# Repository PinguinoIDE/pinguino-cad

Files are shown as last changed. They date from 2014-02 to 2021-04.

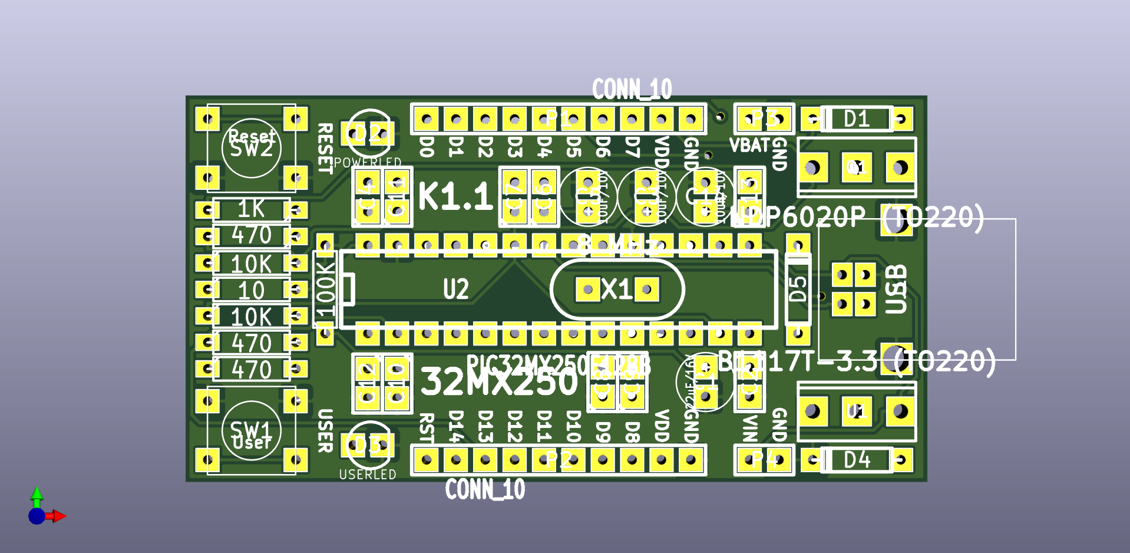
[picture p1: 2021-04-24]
boards/32MX250/K1.1/32mx2xx.png

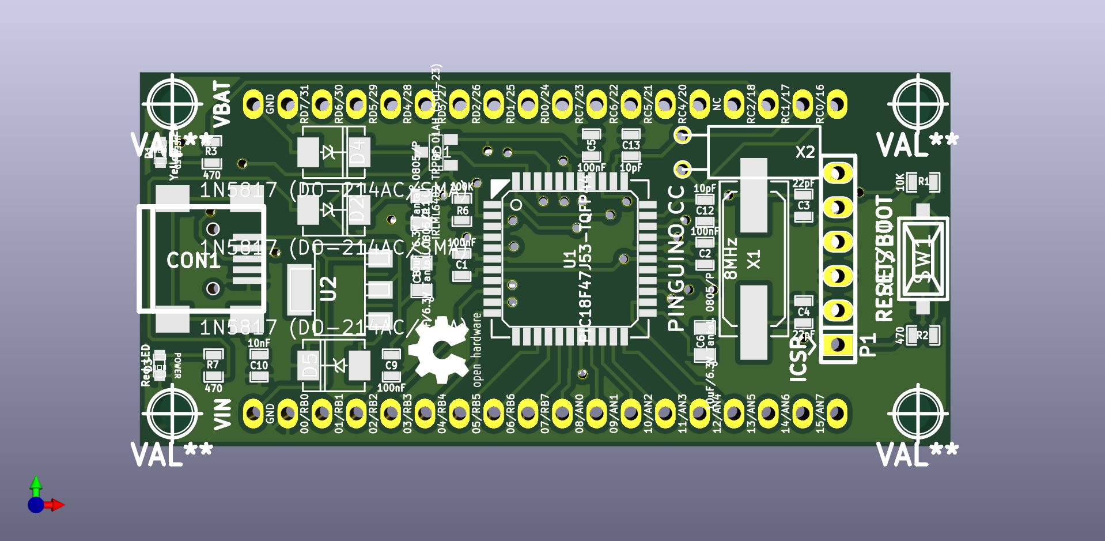
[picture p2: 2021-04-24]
boards/47J53/A1.2/Pinguino47j53A.png

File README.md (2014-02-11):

Most of the Pinguino boards or extensions are designed with Kicad.

KiCad is an EDA software suite for the creation of professional schematics and printed circuit boards up to 16 layers. KiCad runs on Windows, Linux and Apple OS X and is released under the open-source GNU GPL v2 free of charge. With Kicad you can do the following :

<ul>
<li>Schematic design.
<li>Netlist creation in multiple formats (PCBNew, OrCAD, CadStar, Spice, etc...).
<li>PCB design
<li>3D visualization of your PCB
<li>Fabrication outputs generation (Gerber, drill files and whatever can be needed to manufacture a PCB.)
</ul>

For a more detailed explanation please refer to the official site : http://www.kicad-pcb.org

For a better result we use libraries, modules en 3D packages from Walter : http://smisioto.no-ip.org/elettronica/kicad/kicad-en.htm

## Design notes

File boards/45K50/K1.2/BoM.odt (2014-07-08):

### Pinguino 45K50

### Bill Of Components

Resistors

- 3 x 470 Ohm (Yellow - Purple - Black - Black)
- 1 x 10K Ohm (Brown - Black - Orange)

Capacitors

- 2 x 100nF (marked as 104)
- 1 x 220nF (marked as 224)

Diodes

- 1 x 3mm Red LED (+/anode = long lead)
- 1 x 3mm Yellow LED (+/anode = long lead)

Connectors

- 1 x USB Type-B Female
- 1 x 40-pin 2.54mm header strip
- 1 x 40-pin 2.54mm round female header strip)
- Others
- 1 x 2-pin Push Button
- 1 x PIC18F45K50
- 1 x PCB

Optional

- 1 x 8 MHz crystal
- 2 x 22pF (marked as 22)
- 1 x 22uF (polarized, marked as 10uF)
- 1 x 100nF (marked as 104)
- 1x LM7805

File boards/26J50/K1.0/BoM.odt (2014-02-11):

### Bill Of Components

Resistors

- 2 x 470 Ohm (Yellow - Purple - Black - Black)
- 1 x 10 Ohm (Brown - Black - Black - Gold)
- 1 x 10K Ohm (Brown - Black - Orange)

Capacitors

- 2 x 22pF (marked as 22)
- 1 x 10uF (polarized, marked as 10uF)
- 2 x 100nF (marked as 104)

Diodes

- 1 x 3mm Red LED (+/anode = long lead)
- 1 x BZX85C3V3 (3.3V Zener Diode, NB: black band denotes cathode)

Connectors

- 1 x USB Type-B Female
- 1 x 40-pin 2.54mm header strip
- 1 x 40-pin 2.54mm round female header strip)

Others

- 1 x Push Button
- 1 x 8- or 20 MHz crystal
- 1 x PIC18F26J50
- 1 x PCB

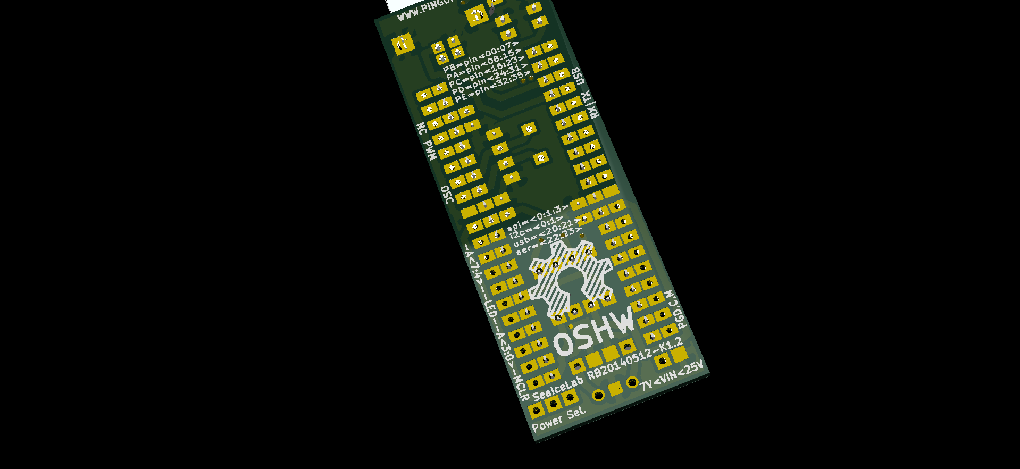
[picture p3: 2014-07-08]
boards/45K50/K1.2/Pinguino45K50-B.png

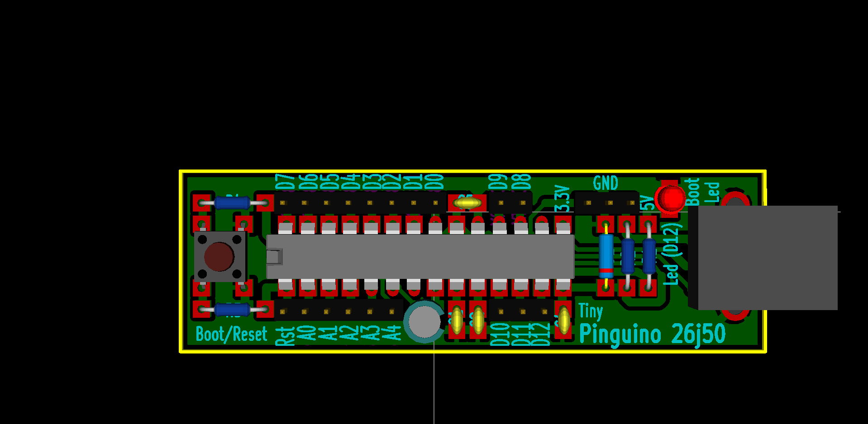
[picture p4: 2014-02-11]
boards/26J50/K1.0/Pinguino26j50.png

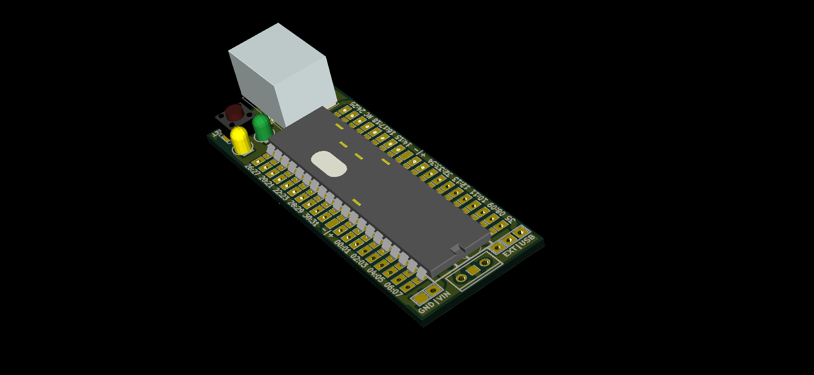
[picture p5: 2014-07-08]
boards/45K50/K1.2/Pinguino45K50-F.png

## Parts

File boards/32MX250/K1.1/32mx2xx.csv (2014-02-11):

Id | Référence | Boitier | Quantité | Désignation | Fournisseur et réf.
1 | D2 | LED-3MM | 1 | POWERLED
2 | D3 | LED-3MM | 1 | USERLED
3 | P2,P1 | SIL-10 | 2 | CONN_10
4 | C7,C10,C12,C13,C2,C4,C6,C11 | C1 | 8 | 100nF
5 | C8,C9 | C1 | 2 | 22pF
6 | D4,D5,D1 | D3 | 3 | 1N5817 (DO-214AC)
7 | P3,P4 | SIL-2 | 2 | Ext. Power
8 | R1 | R3 | 1 | 100K
9 | R2 | R3 | 1 | 1K
10 | R3,R7,R8 | R3 | 3 | 470
11 | R4 | R3 | 1 | 10
12 | R5,R6 | R3 | 2 | 10K
13 | SW1 | SW_PUSH_SMALL | 1 | User
14 | SW2 | SW_PUSH_SMALL | 1 | Reset
15 | X1 | HC-49V | 1 | 8 MHz
16 | C1 | C1V5 | 1 | 22uF/16V
17 | C3,C5,C14 | C1V5 | 3 | 10uF/10V
18 | G2 | Logo_silk_OSHW_6x6mm | 1 | LOGO
19 | J1 | USB_B | 1 | USB
20 | Q1 | to220 | 1 | NDP6020P (TO220)
21 | U1 | to220 | 1 | B1117T-3.3 (TO220)
22 | U2 | dil_28-300 | 1 | PIC32MX250F128B
23 | VAL | logo1in | 1 | logo1in
24 | G*** | Logo_silk_WEEE_3.4x5mm | 1 | LOGO

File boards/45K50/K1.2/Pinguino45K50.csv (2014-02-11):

Id | Référence | Boitier | Quantité | Désignation | Fournisseur et réf.
1 | P6 | pin_strip_6 | 1 | PORT_A
2 | C1,C2 | cnp_3mm_disc | 2 | 22pF
3 | C3 | CP_5x11mm | 1 | 10uF
4 | C4 | cnp_7x6mm | 1 | 220nF
5 | C5 | cnp_3mm_disc | 1 | 100nF
6 | J1 | conn_usb_B | 1 | USB-B
7 | K1 | pin_strip_3 | 1 | PWM
8 | P3 | pin_strip_2 | 1 | UART
9 | P4 | pin_strip_8 | 1 | PORT_B
10 | P5 | pin_strip_2 | 1 | +/-
11 | R1 | RC03 | 1 | 10K
12 | R2 | RC03 | 1 | 470
13 | SW1 | PCB_PUSH | 1 | But
14 | U1 | dil_28-300_socket | 1 | PIC18F2550
15 | X1 | crystal_hc-49u | 1 | 20MHz
16 | D1 | led_3mm_red | 1 | Led

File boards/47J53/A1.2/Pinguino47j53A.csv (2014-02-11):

Id | Référence | Boitier | Quantité | Désignation | Fournisseur et réf.
1 | C6,C11,C8 | c_0805 | 3 | 10uF/6.3V Tantal. 0805/P
2 | J1,J2 | pin_strip_20 | 2 | HEADER_20
3 | C4,C3 | SM0603_Capa | 2 | 22pF
4 | C2,C1,C5,C9,C7 | SM0603_Capa | 5 | 100nF
5 | D1 | LED-0603 | 1 | Yellow LED
6 | U1 | lqfp44 | 1 | PIC18F47J53-TQFP44
7 | D3 | LED-0603 | 1 | Red LED
8 | R3,R2,R7 | SM0603_Resistor | 3 | 470
9 | R1 | SM0603_Resistor | 1 | 10K
10 | R5,R4,R6 | SM0603_Resistor | 3 | 100K
11 | SW1 | smd_push | 1 | RESET
12 | LOGO1 | LOGO | 1 | OPEN_HARDWARE_1
13 | CON1 | USB_MINI_B | 1 | USB-MINI-B
14 | C10 | SM0603_Capa | 1 | 10nF
15 | D2,D4,D5 | DO-214AC(SMA) | 3 | 1N5817 (DO-214AC/SMA)
16 | X1 | Q_49U3HMS | 1 | 8MHz
17 | P1 | pin_strip_6 | 1 | ICSP
18 | U2 | sot223 | 1 | AMS1117-3.3V (SOT-223)
19 | U6 | Logo_silk_WEEE_8x10mm | 1 | DIAMOND1
20 | U3 | Logo_silk_OSHW_6x6mm | 1 | DIAMOND1
21 | Q1 | SOT23 | 1 | IRLML6402 TRPBF 01AH (SOT-23)
22 | hole_3mm_1,hole_3mm_4,hole_3mm_2,hole_3mm_3 | hole_3mm | 4 | VAL**
23 | C12,C13 | SM0603_Capa | 2 | 10pF
24 | X2 | QMONTRE | 1 | 32768Hz

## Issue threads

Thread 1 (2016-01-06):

Wrong board?

josla972, 2016-01-06:
When I open Pinguino45K50.brd in Pcbnew, the layout seems to differ from the PCB shown on the wiki pages. Also, it says PIC18F26J50 on the board which is not the correct PIC processor.

rblanchot, 2016-01-11:
Hi,
Sorry for the late response,
The correct file is Pinguino45K50.kicad_pcb

Closed 2016-01-11.

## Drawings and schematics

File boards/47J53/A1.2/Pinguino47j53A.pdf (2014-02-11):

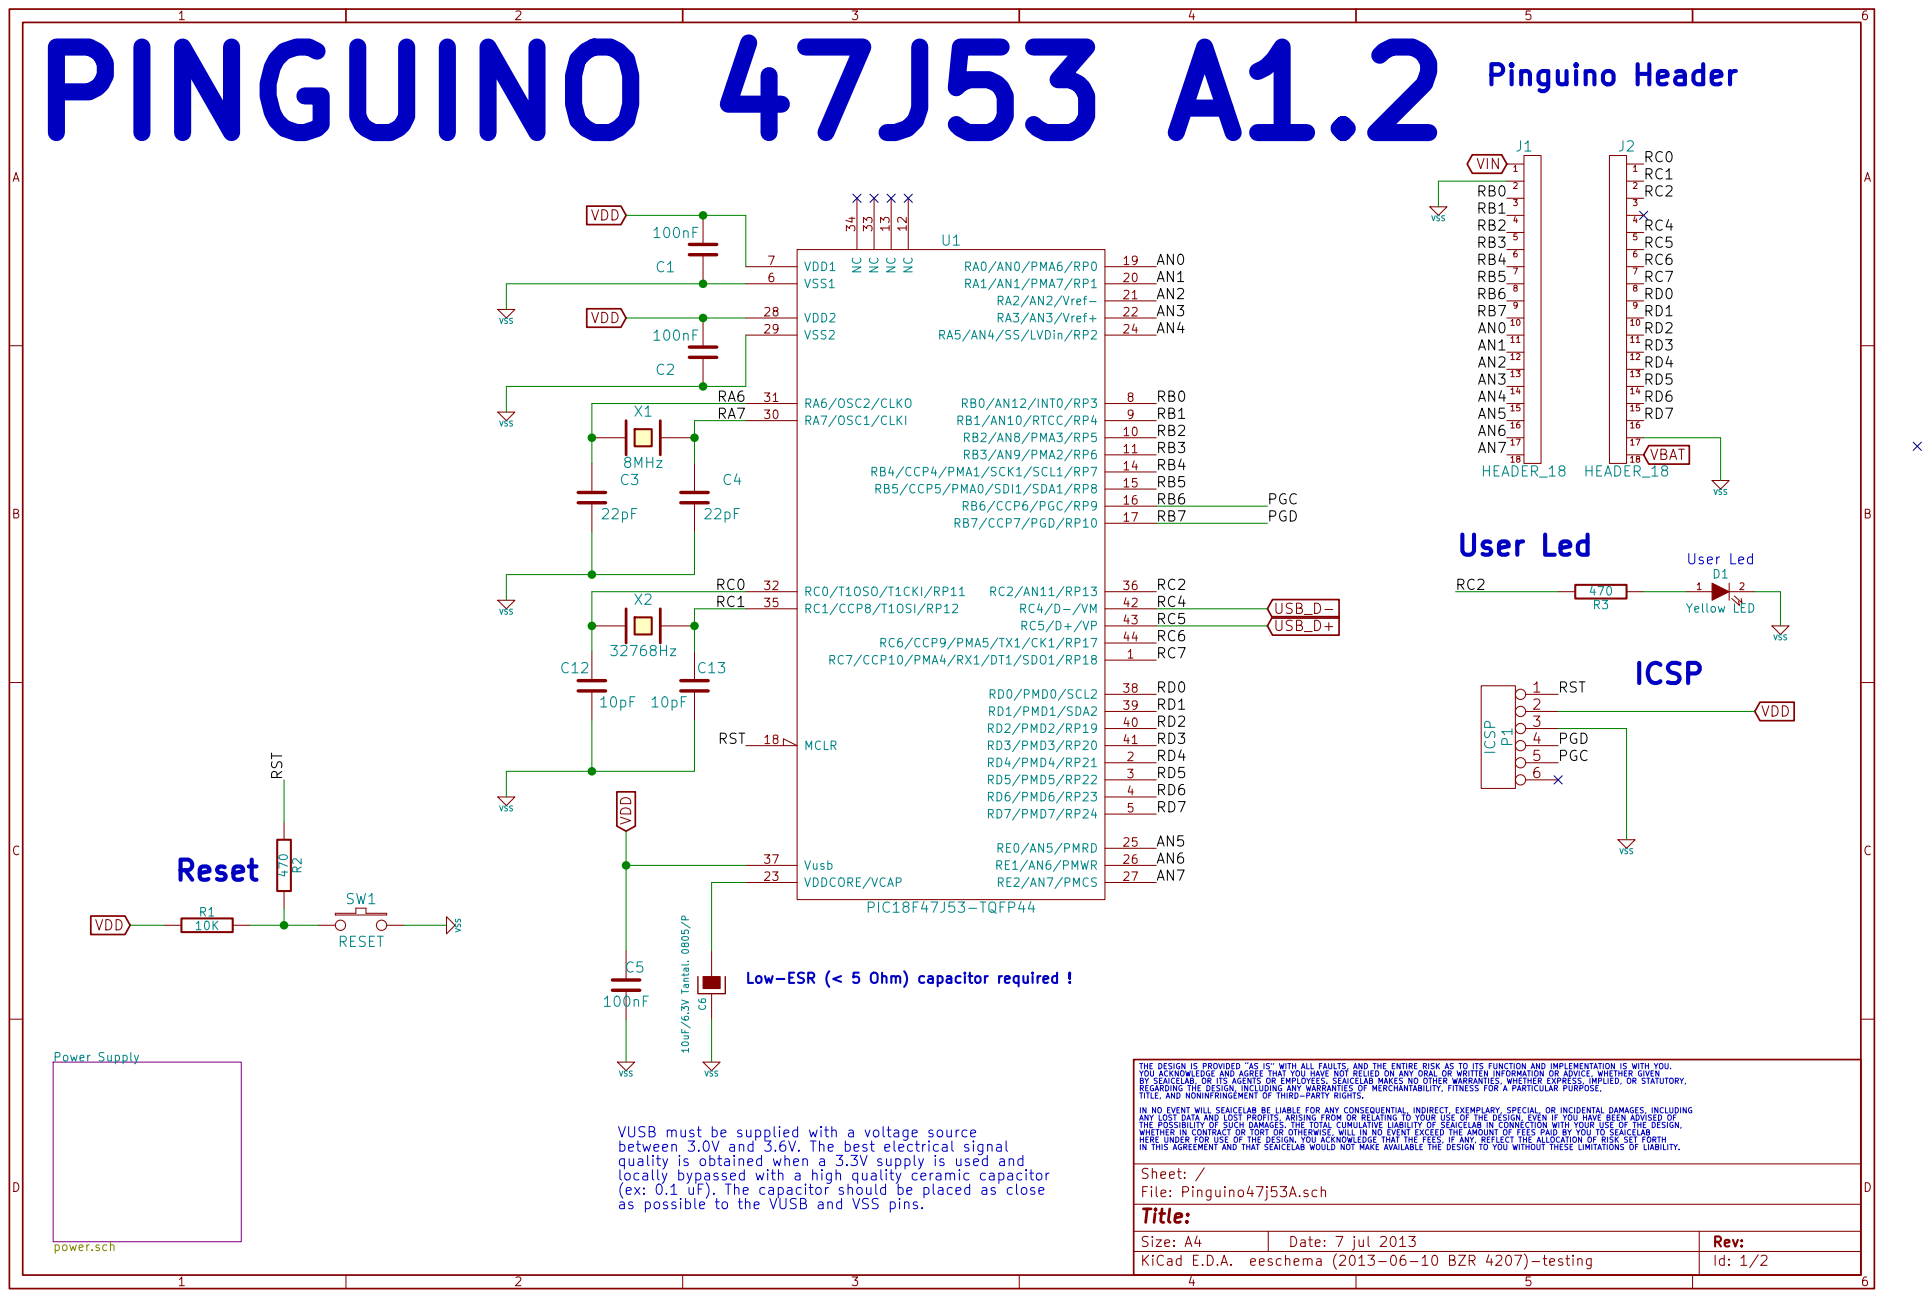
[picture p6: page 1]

100nF VUSB must be supplied with a voltage source

THE DESIGN IS PROVIDED AS IS WITH ALL FAULTS, AND THE ENTIRE RISK AS TO ITS FUNCTION AND IMPLEMENTATION IS WITH YOU. YOU ACKNOWLEDGE AND AGREE THAT YOU HAVE NOT RELIED ON ANY ORAL OR WRITTEN INFORMATION OR ADVICE, WHETHER GIVEN
BY SEAICELAB, OR ITS AGENTS OR EMPLOYEES. SEAICELAB MAKES NO OTHER WARRANTIES, WHETHER EXPRESS, IMPLIED, OR STATUTORY, REGARDING THE DESIGN, INCLUDING ANY WARRANTIES OF MERCHANTABILITY, FITNESS FOR A PARTICULAR PURPOSE, TITLE, AND NONINFRINGEMENT OF THIRD-PARTY RIGHTS.

IN NO EVENT WILL SEAICELAB BE LIABLE FOR ANY CONSEQUENTIAL, INDIRECT, EXEMPLARY, SPECIAL, OR INCIDENTAL DAMAGES, INCLUDING
ANY LOST DATA AND LOST PROFITS, ARISING FROM OR RELATING TO YOUR USE OF THE DESIGN, EVEN IF YOU HAVE BEEN ADVISED OF
THE POSSIBILITY OF SUCH DAMAGES. THE TOTAL CUMULATIVE LIABILITY OF SEAICELAB IN CONNECTION WITH YOUR USE OF THE DESIGN, WHETHER IN CONTRACT OR TORT OR OTHERWISE, WILL IN NO EVENT EXCEED THE AMOUNT OF FEES PAID BY YOU TO SEAICELAB HERE UNDER FOR USE OF THE DESIGN. YOU ACKNOWLEDGE THAT THE FEES, IF ANY, REFLECT THE ALLOCATION OF RISK SET FORTH

between 3.0V and 3.6V. The best electrical signal
quality is obtained when a 3.3V supply is used and
locally bypassed with a high quality ceramic capacitor
(ex: 0.1 uF). The capacitor should be placed as close
as possible to the VUSB and VSS pins.

IN THIS AGREEMENT AND THAT SEAICELAB WOULD NOT MAKE AVAILABLE THE DESIGN TO YOU WITHOUT THESE LIMITATIONS OF LIABILITY.

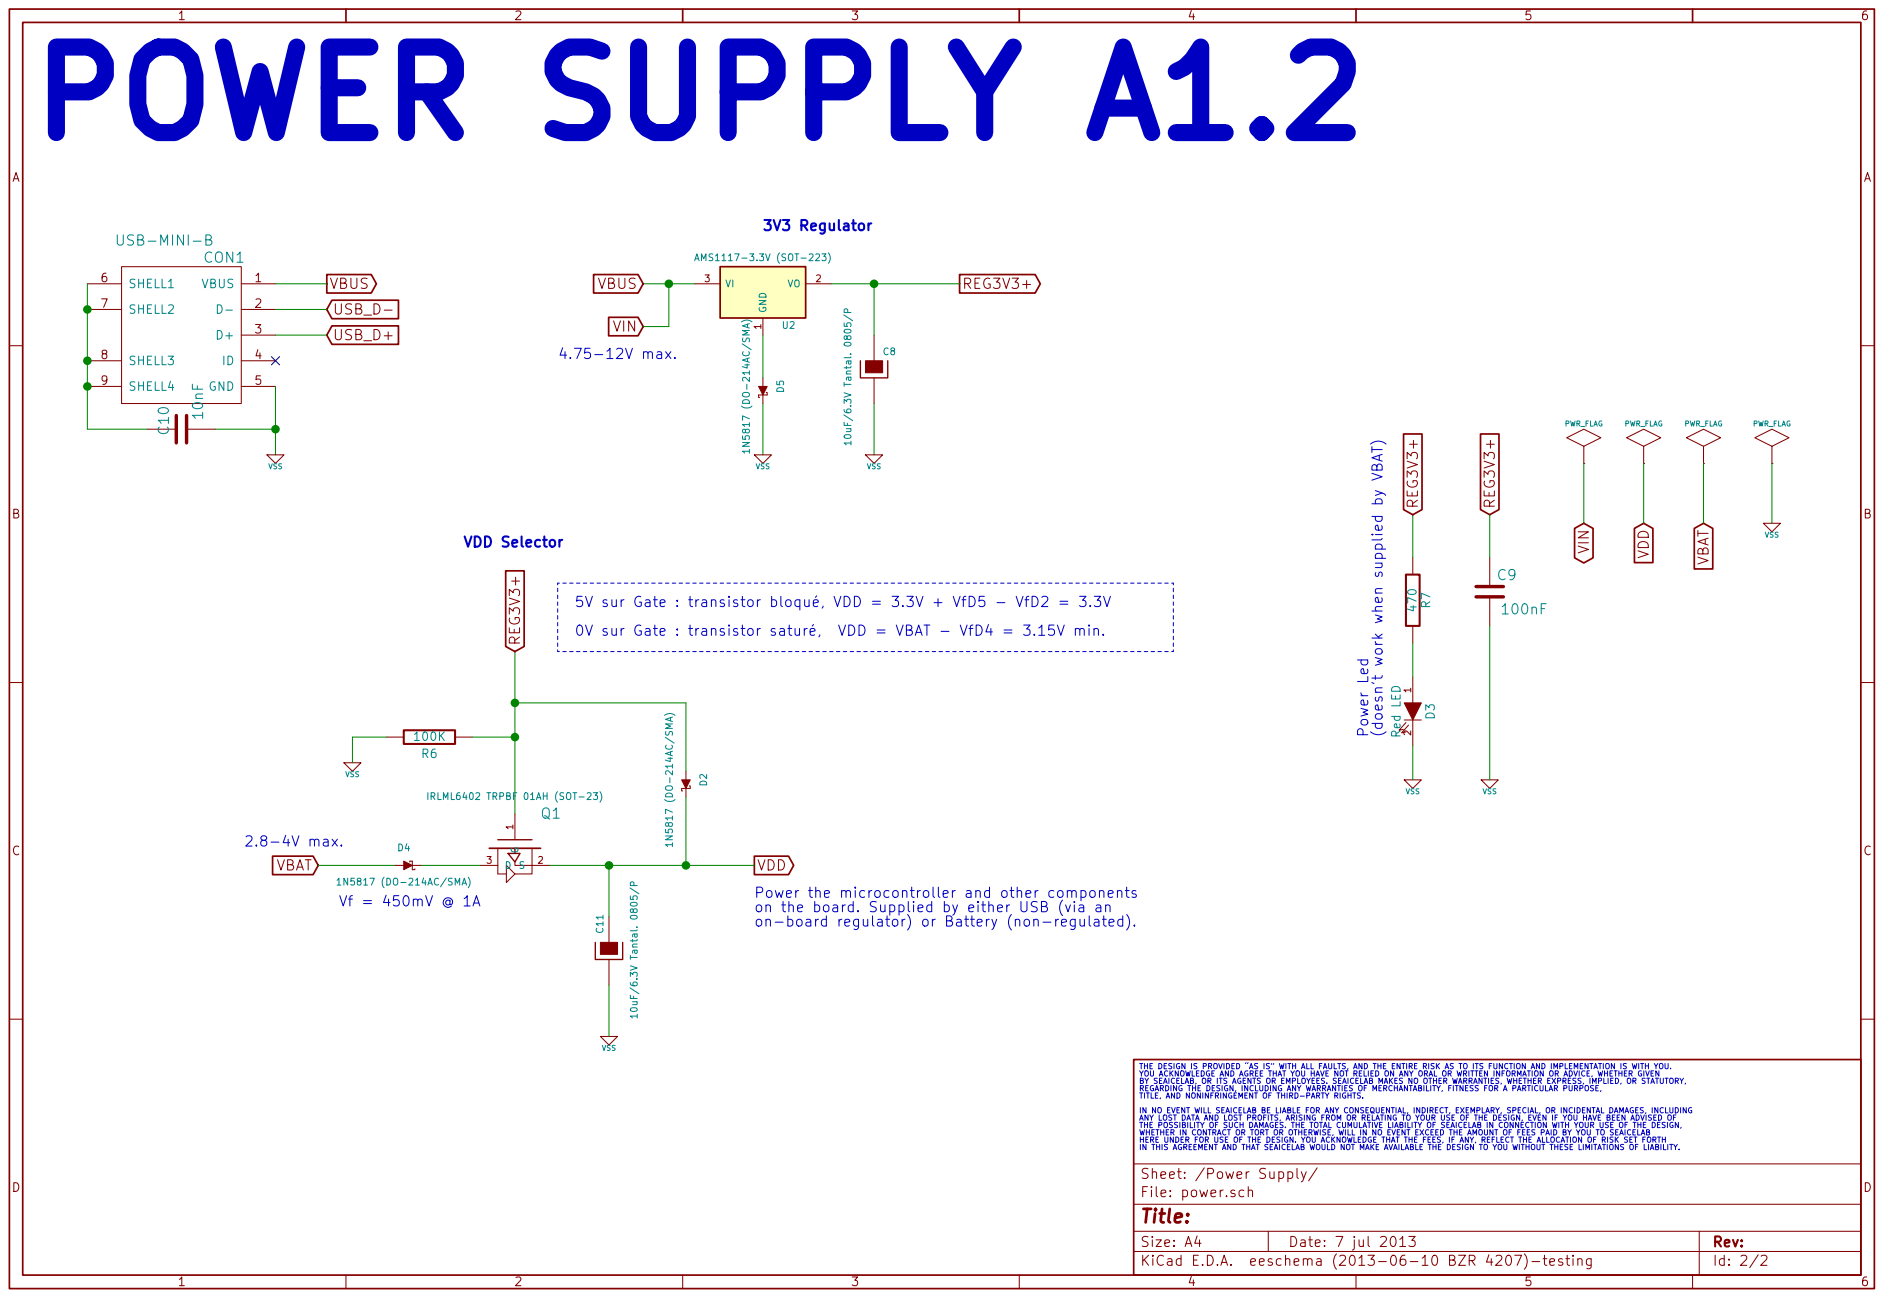
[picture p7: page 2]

1 VO 2 VI 3 U2 AMS1117-3.3V (SOT-223) VBUS 1 D- 2 D+ 3

IN THIS AGREEMENT AND THAT SEAICELAB WOULD NOT MAKE AVAILABLE THE DESIGN TO YOU WITHOUT THESE LIMITATIONS OF LIABILITY. VDD Selector VBAT

5V sur Gate : transistor bloqué, VDD = 3.3V + VfD5 - VfD2 = 3.3V

Power the microcontroller and other components
on the board. Supplied by either USB (via an

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

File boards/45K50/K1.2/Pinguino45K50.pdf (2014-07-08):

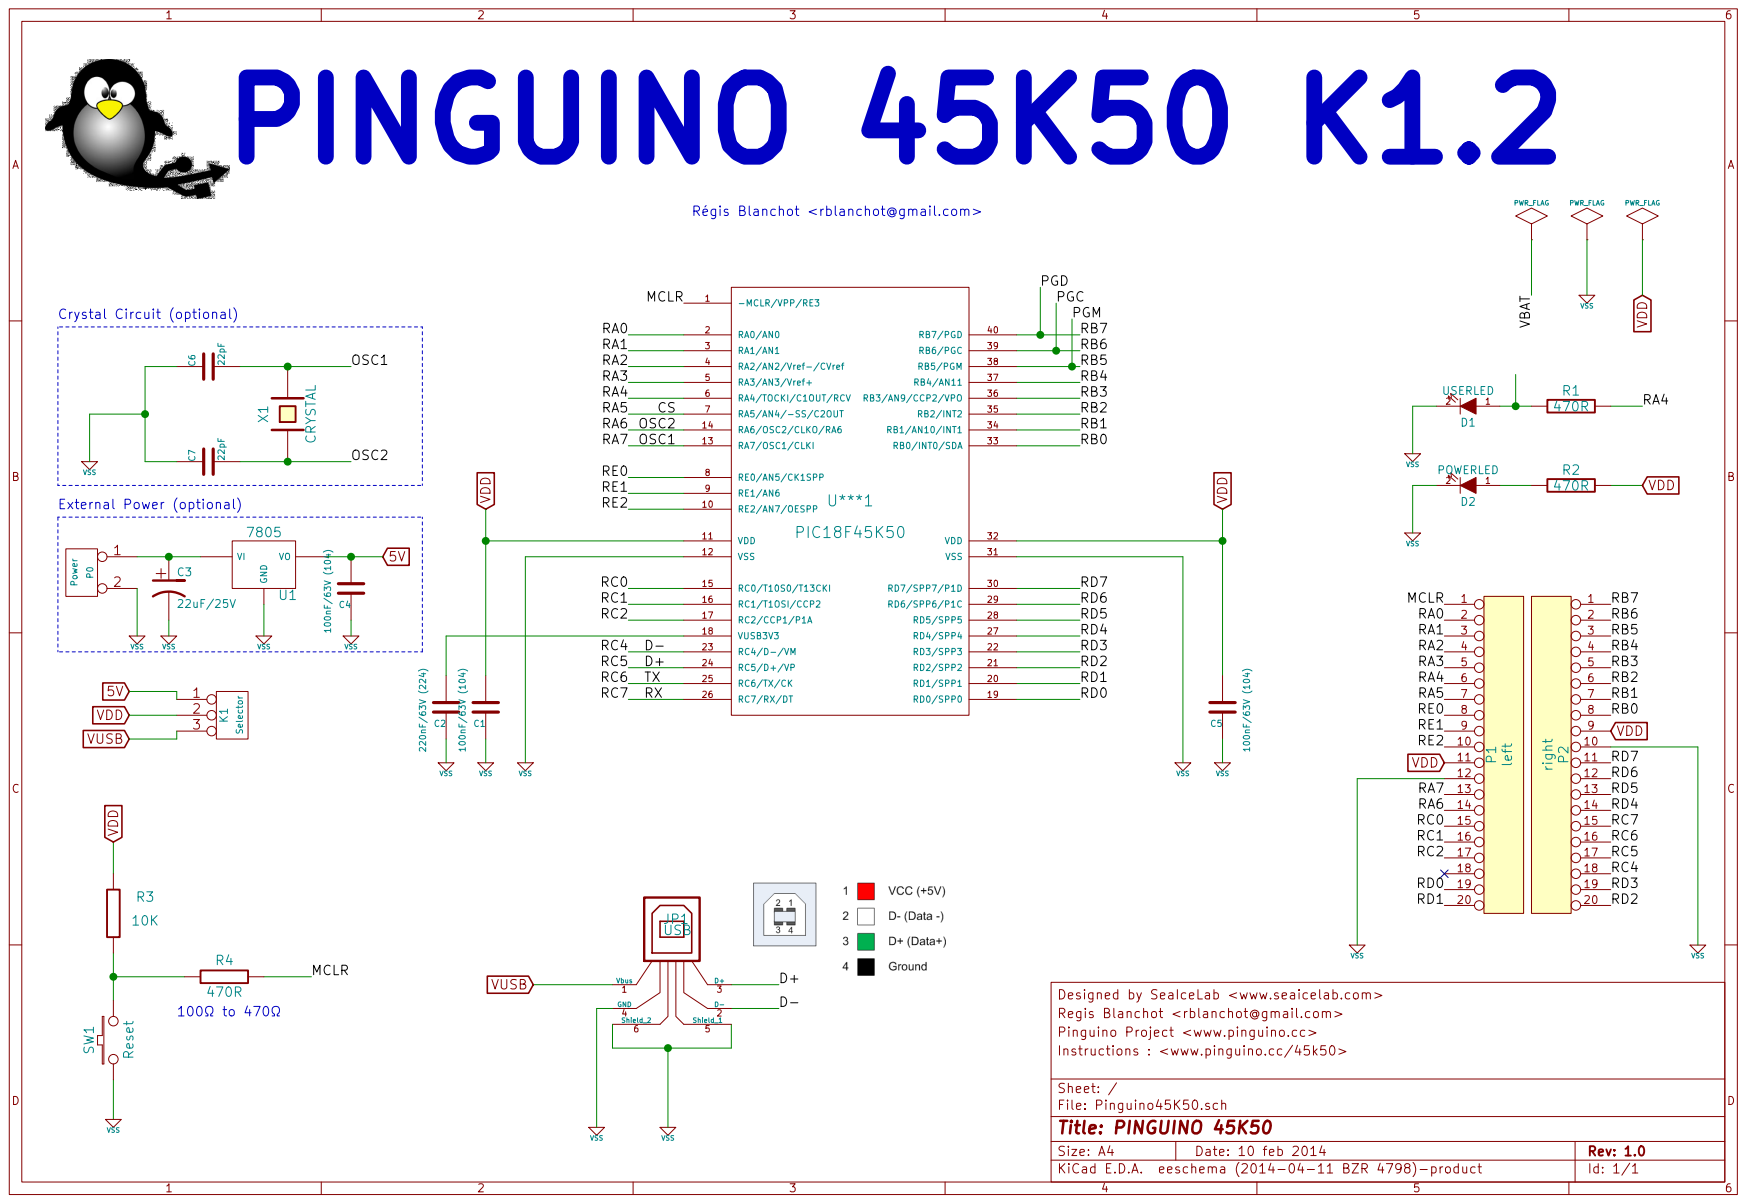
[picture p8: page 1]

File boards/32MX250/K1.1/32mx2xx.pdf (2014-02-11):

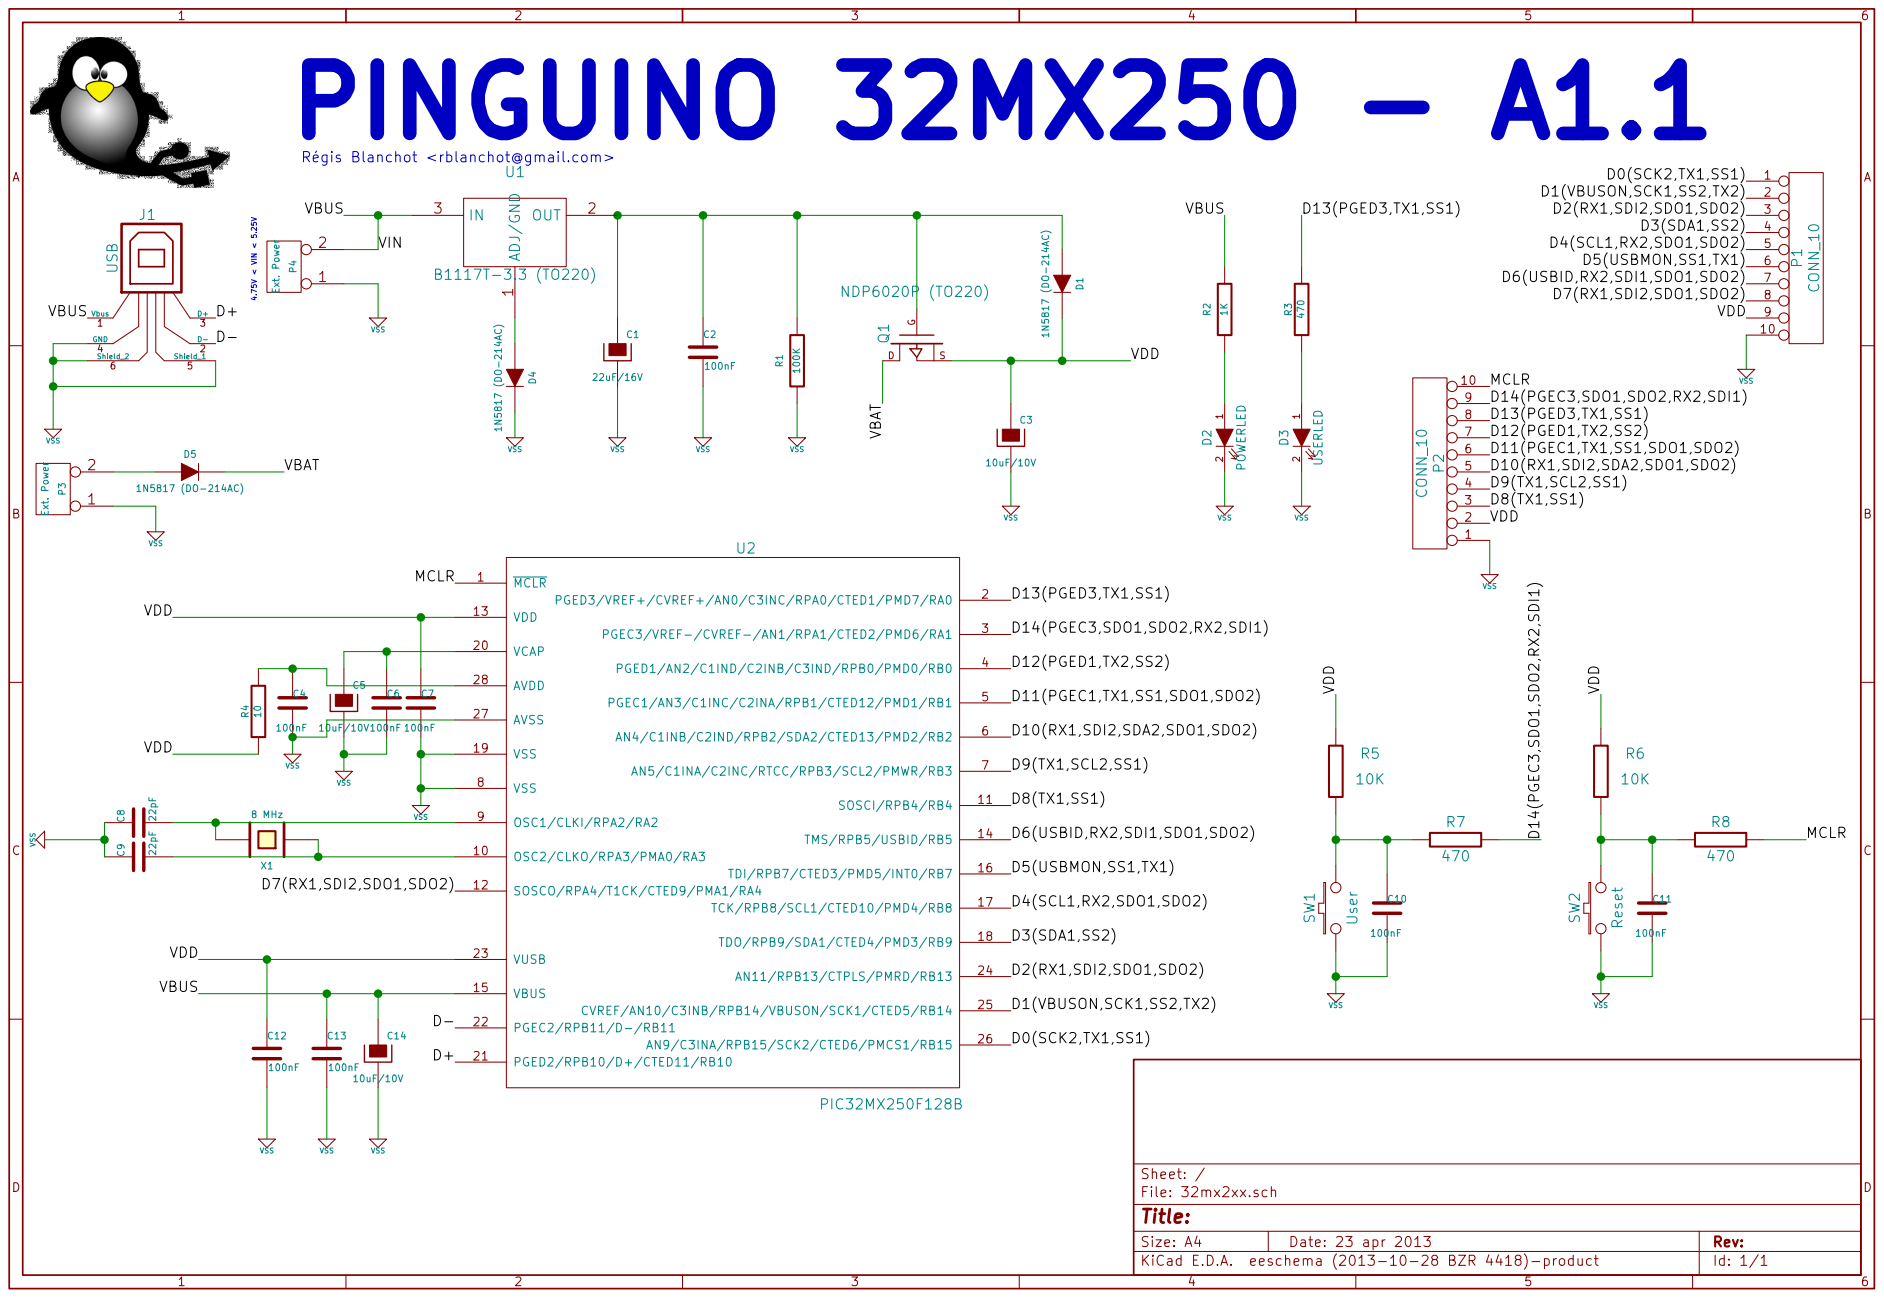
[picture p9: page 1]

Régis Blanchot <rblanchot@gmail.com>

Id: 1/1 Title: File: 32mx2xx.sch Sheet: / X1
D7(RX1,SDI2,SDO1,SDO2) C12

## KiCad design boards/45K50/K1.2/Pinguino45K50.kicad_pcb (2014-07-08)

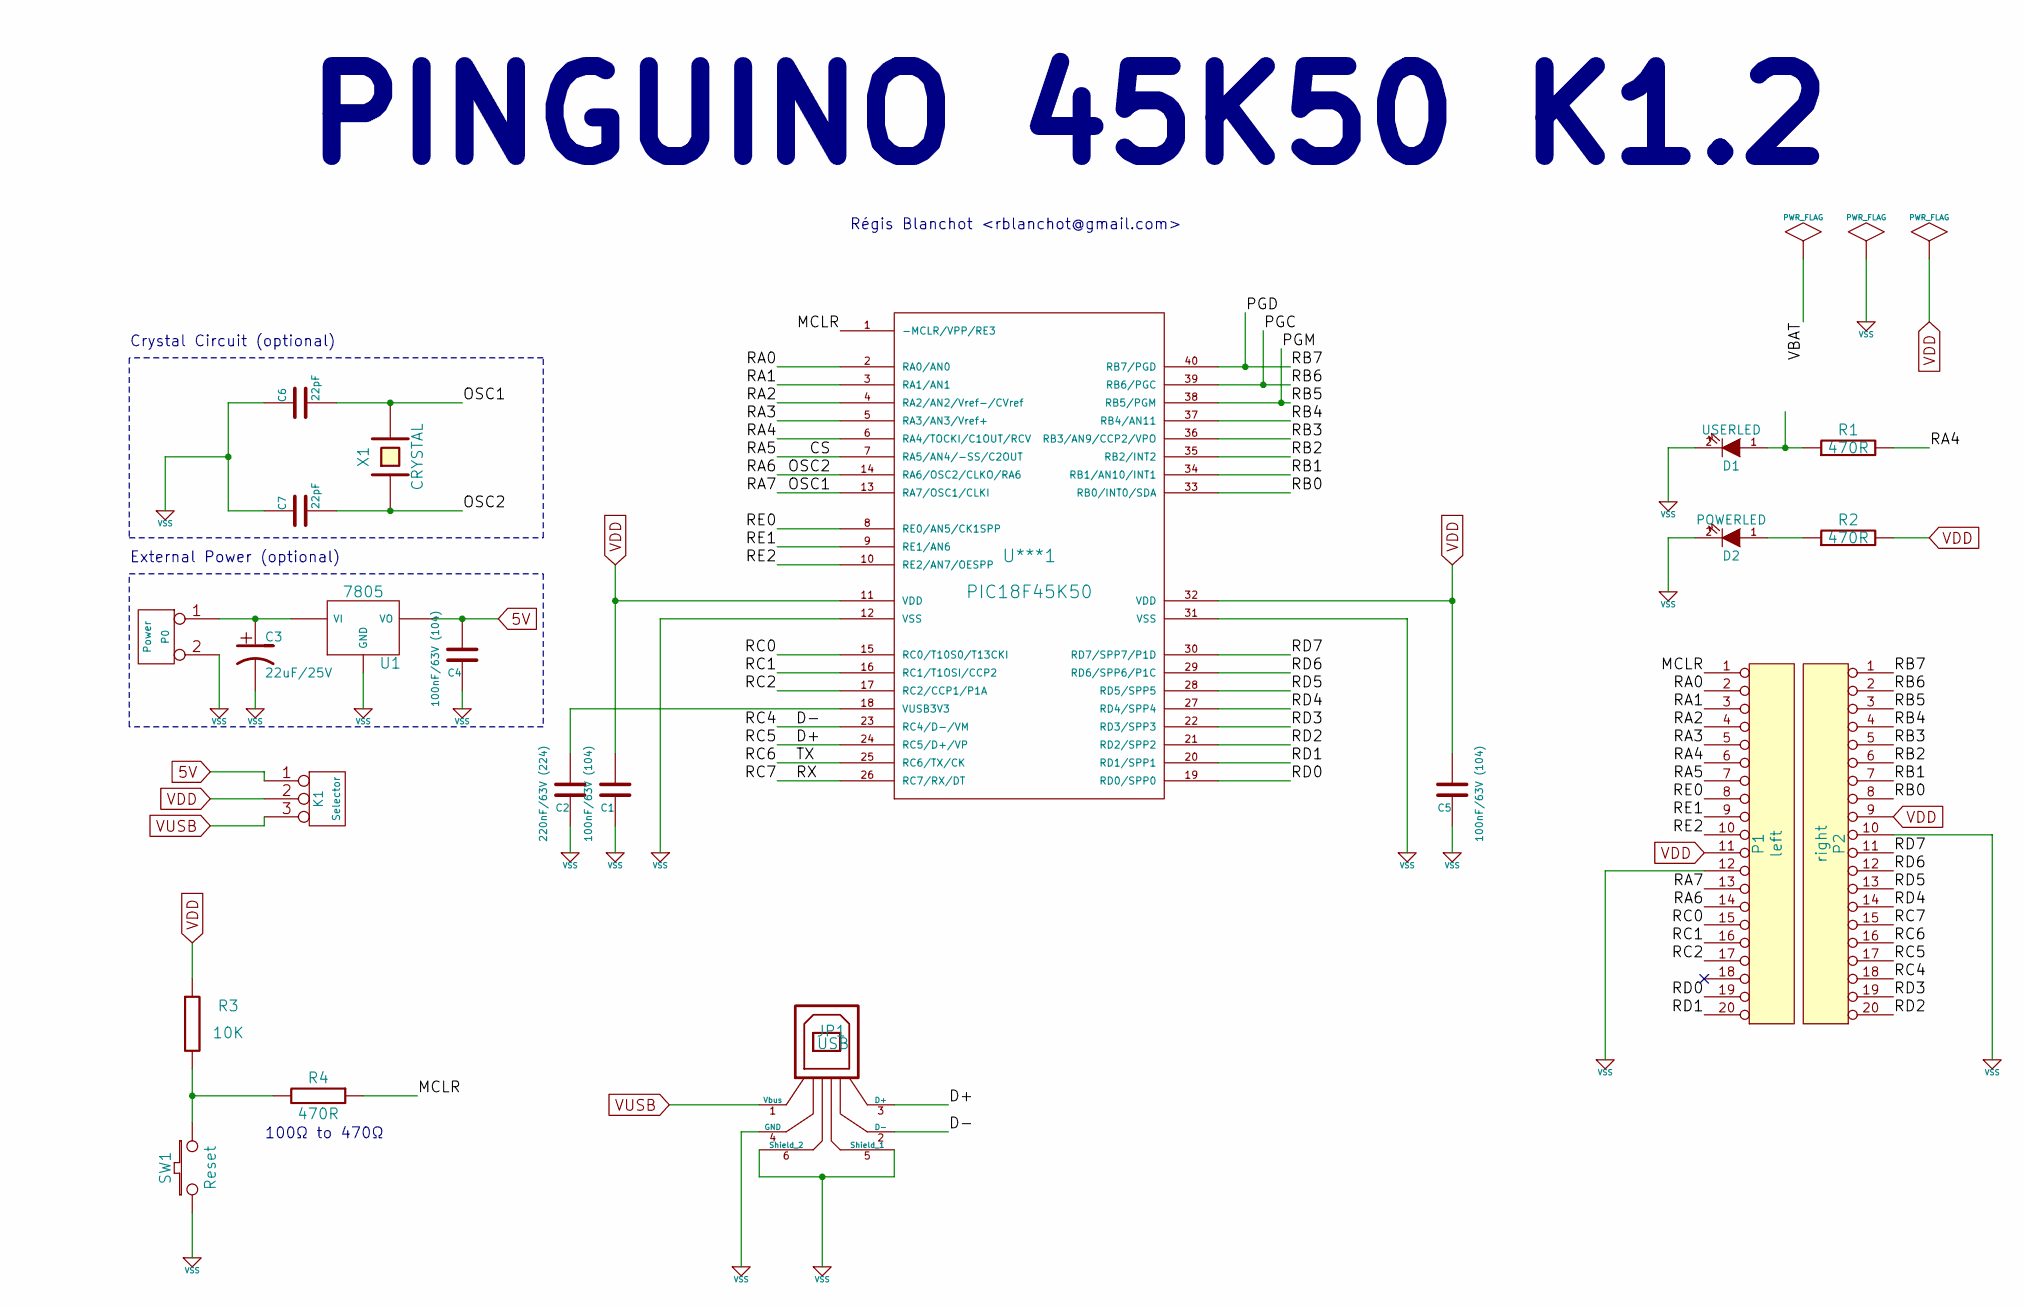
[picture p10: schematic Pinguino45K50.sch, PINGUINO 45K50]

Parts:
C1, C4, C5: 100nF/63V (104)
C2: 220nF/63V (224)
C3: 22uF/25V
C6, C7: 22pF
D1: USERLED
D2: POWERLED
JP1: USB
K1: Selector
P0: Power
P1: left
P2: right
R1, R2, R4: 470R
R3: 10K
SW1: Reset
U1: 7805
U***1: PIC18F45K50
X1: CRYSTAL

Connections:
5V: C4.2, K1.1, U1.VO
/CS: P1.7, U***1.7 (RA5/AN4/-SS/C2OUT)
/D+: JP1.3 (D+), P2.17, U***1.24 (RC5/D+/VP)
/D-: JP1.2 (D-), P2.18, U***1.23 (RC4/D-/VM)
/MCLR: P1.1, R4.1, U***1.1 (-MCLR/VPP/RE3)
/OSC1: C6.2, P1.13, U***1.13 (RA7/OSC1/CLKI), X1.2
/OSC2: C7.2, P1.14, U***1.14 (RA6/OSC2/CLKO/RA6), X1.1
/PGC: P2.2, U***1.39 (RB6/PGC)
/PGD: P2.1, U***1.40 (RB7/PGD)
/PGM: P2.3, U***1.38 (RB5/PGM)
/RA0: P1.2, U***1.2 (RA0/AN0)
/RA1: P1.3, U***1.3 (RA1/AN1)
/RA2: P1.4, U***1.4 (RA2/AN2/Vref-/CVref)
/RA3: P1.5, U***1.5 (RA3/AN3/Vref+)
/RA4: P1.6, R1.2, U***1.6 (RA4/TOCKI/C1OUT/RCV)
/RB0: P2.8, U***1.33 (RB0/INT0/SDA)
/RB1: P2.7, U***1.34 (RB1/AN10/INT1)
/RB2: P2.6, U***1.35 (RB2/INT2)
/RB3: P2.5, U***1.36 (RB3/AN9/CCP2/VPO)
/RB4: P2.4, U***1.37 (RB4/AN11)
/RC0: P1.15, U***1.15 (RC0/T10S0/T13CKI)
/RC1: P1.16, U***1.16 (RC1/T1OSI/CCP2)
/RC2: P1.17, U***1.17 (RC2/CCP1/P1A)
/RC6: P2.16, U***1.25 (RC6/TX/CK)
/RC7: P2.15, U***1.26 (RC7/RX/DT)
/RD0: P1.19, U***1.19 (RD0/SPP0)
/RD1: P1.20, U***1.20 (RD1/SPP1)
/RD2: P2.20, U***1.21 (RD2/SPP2)
/RD3: P2.19, U***1.22 (RD3/SPP3)
/RD4: P2.14, U***1.27 (RD4/SPP4)
/RD5: P2.13, U***1.28 (RD5/SPP5)
/RD6: P2.12, U***1.29 (RD6/SPP6/P1C)
/RD7: P2.11, U***1.30 (RD7/SPP7/P1D)
/RE0: P1.8, U***1.8 (RE0/AN5/CK1SPP)
/RE1: P1.9, U***1.9 (RE1/AN6)
/RE2: P1.10, U***1.10 (RE2/AN7/OESPP)
unnamed: C2.2, U***1.18 (VUSB3V3)
unnamed: C3.1, P0.1, U1.VI
unnamed: D1.1 (A), R1.1
unnamed: D2.1 (A), R2.1
unnamed: R3.2, R4.2, SW1.2
VDD: C1.2, C5.2, K1.2 (PM), P1.11, P2.9, R2.2, R3.1, U***1.11 (VDD), U***1.32 (VDD)
VSS: C1.1, C2.1, C3.2, C4.1, C5.1, C6.1, C7.1, D1.2 (K), D2.2 (K), JP1.4 (GND), JP1.5 (Shield_1), JP1.6 (Shield_2), P0.2 (PM), P1.12, P2.10, SW1.1, U1.GND, U***1.12 (VSS), U***1.31 (VSS)
VUSB: JP1.1 (Vbus), K1.3

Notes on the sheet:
Régis Blanchot <rblanchot@gmail.com>
PINGUINO 45K50 K1.2
100Ω to 470Ω
Crystal Circuit (optional)
External Power (optional)

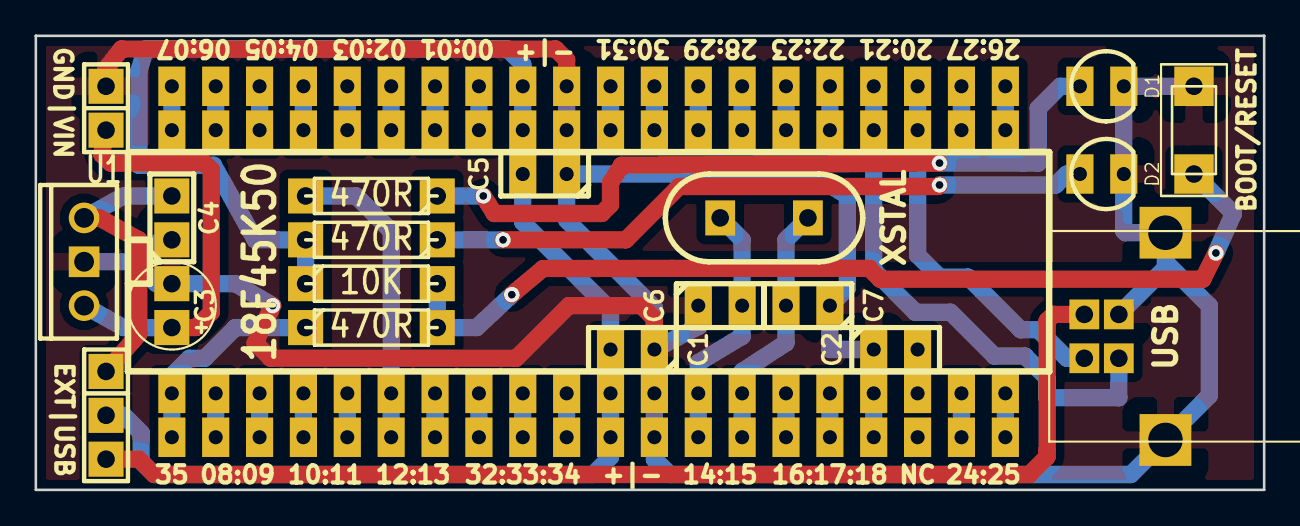
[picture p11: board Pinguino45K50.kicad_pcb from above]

Board: 2 copper layers, 71.1 x 26.3 mm, 23 parts (1 on the bottom side), 44 nets.

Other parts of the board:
Sym: Symbol_OSHW-Logo_SilkScreen_BIG_07Jul2012; Symbol_OSHW-Logo_SilkScreen_BIG

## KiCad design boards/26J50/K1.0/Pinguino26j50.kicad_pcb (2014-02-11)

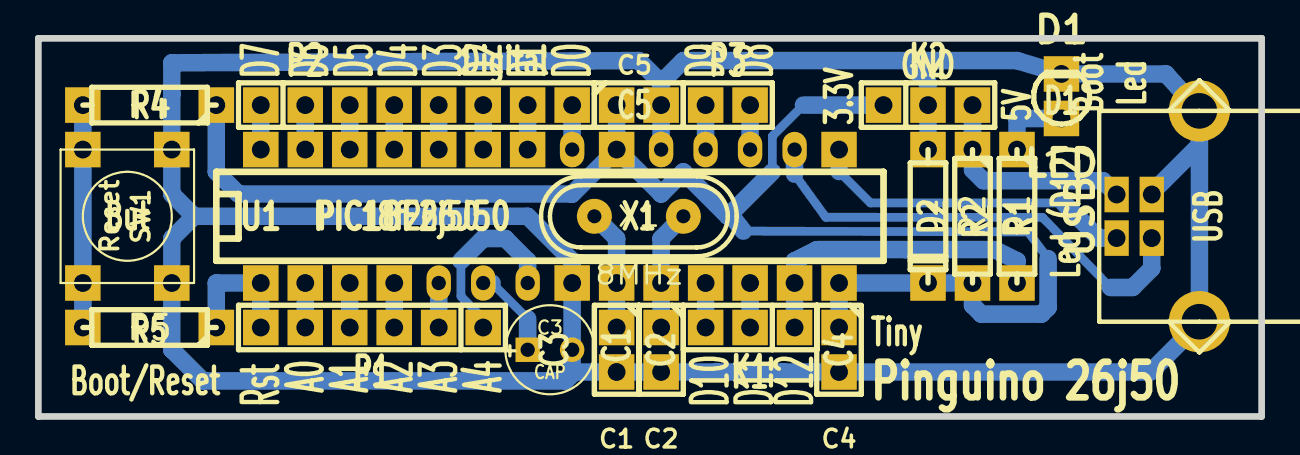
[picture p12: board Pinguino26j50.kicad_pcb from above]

Board: 2 copper layers, 69.9 x 21.6 mm, 20 parts (0 on the bottom side), 29 nets.

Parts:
C1, C2: 22pF; cnp_3mm_disc
C3: CAP; C1V5
C4, C5: 100nF; cnp_3mm_disc
D1: LED; led_3mm_red
D2: BZX85C3V3; D3
JP1: USB; conn_usb_B
K1: PWM; SIL-3
K2: Power; SIL-3
P1: Analog; SIL-6
P2: Digital; SIL-8
P3: UART; SIL-2
R1: 390; R3
R2: 5.6; R3
R4: 10K; R3
R5: 390R; R3
SW1: Reset; SW_PUSH_SMALL
U1: PIC18F26J50; DIP-28__300
X1: 8MHz; crystal_hc-49u

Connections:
3.3V: C4.1, C5.1, D2.2, K2.1, R2.2, R4.1, U1.14, U1.20
5V: JP1.1, K2.3, R2.1
D+: JP1.3, U1.16
D-: JP1.2, U1.15
GND: C1.2, C2.2, C3.2, C4.2, C5.2, D1.2, D2.1, JP1.4, JP1.5, JP1.6, K2.2, SW1.1, U1.8, U1.19
unnamed: P2.2, U1.27
unnamed: P2.4, U1.25
unnamed: P2.6, U1.23
unnamed: D1.1, R1.1
unnamed: P1.1, U1.7
unnamed: K1.1, R1.2, U1.13
unnamed: P2.3, U1.26
unnamed: P3.2, U1.17
unnamed: P3.1, U1.18
unnamed: P2.1, U1.28
unnamed: P2.5, U1.24
unnamed: C2.1, U1.10, X1.2
unnamed: P1.5, U1.2
unnamed: P1.4, U1.3
unnamed: P1.2, U1.5
unnamed: C1.1, U1.9, X1.1
unnamed: C3.1, U1.6
unnamed: K1.3, U1.11
unnamed: P2.8, U1.21
unnamed: K1.2, U1.12
unnamed: P2.7, U1.22
unnamed: P1.3, U1.4
unnamed: R4.2, R5.2, SW1.2
reset: P1.6, R5.1, U1.1

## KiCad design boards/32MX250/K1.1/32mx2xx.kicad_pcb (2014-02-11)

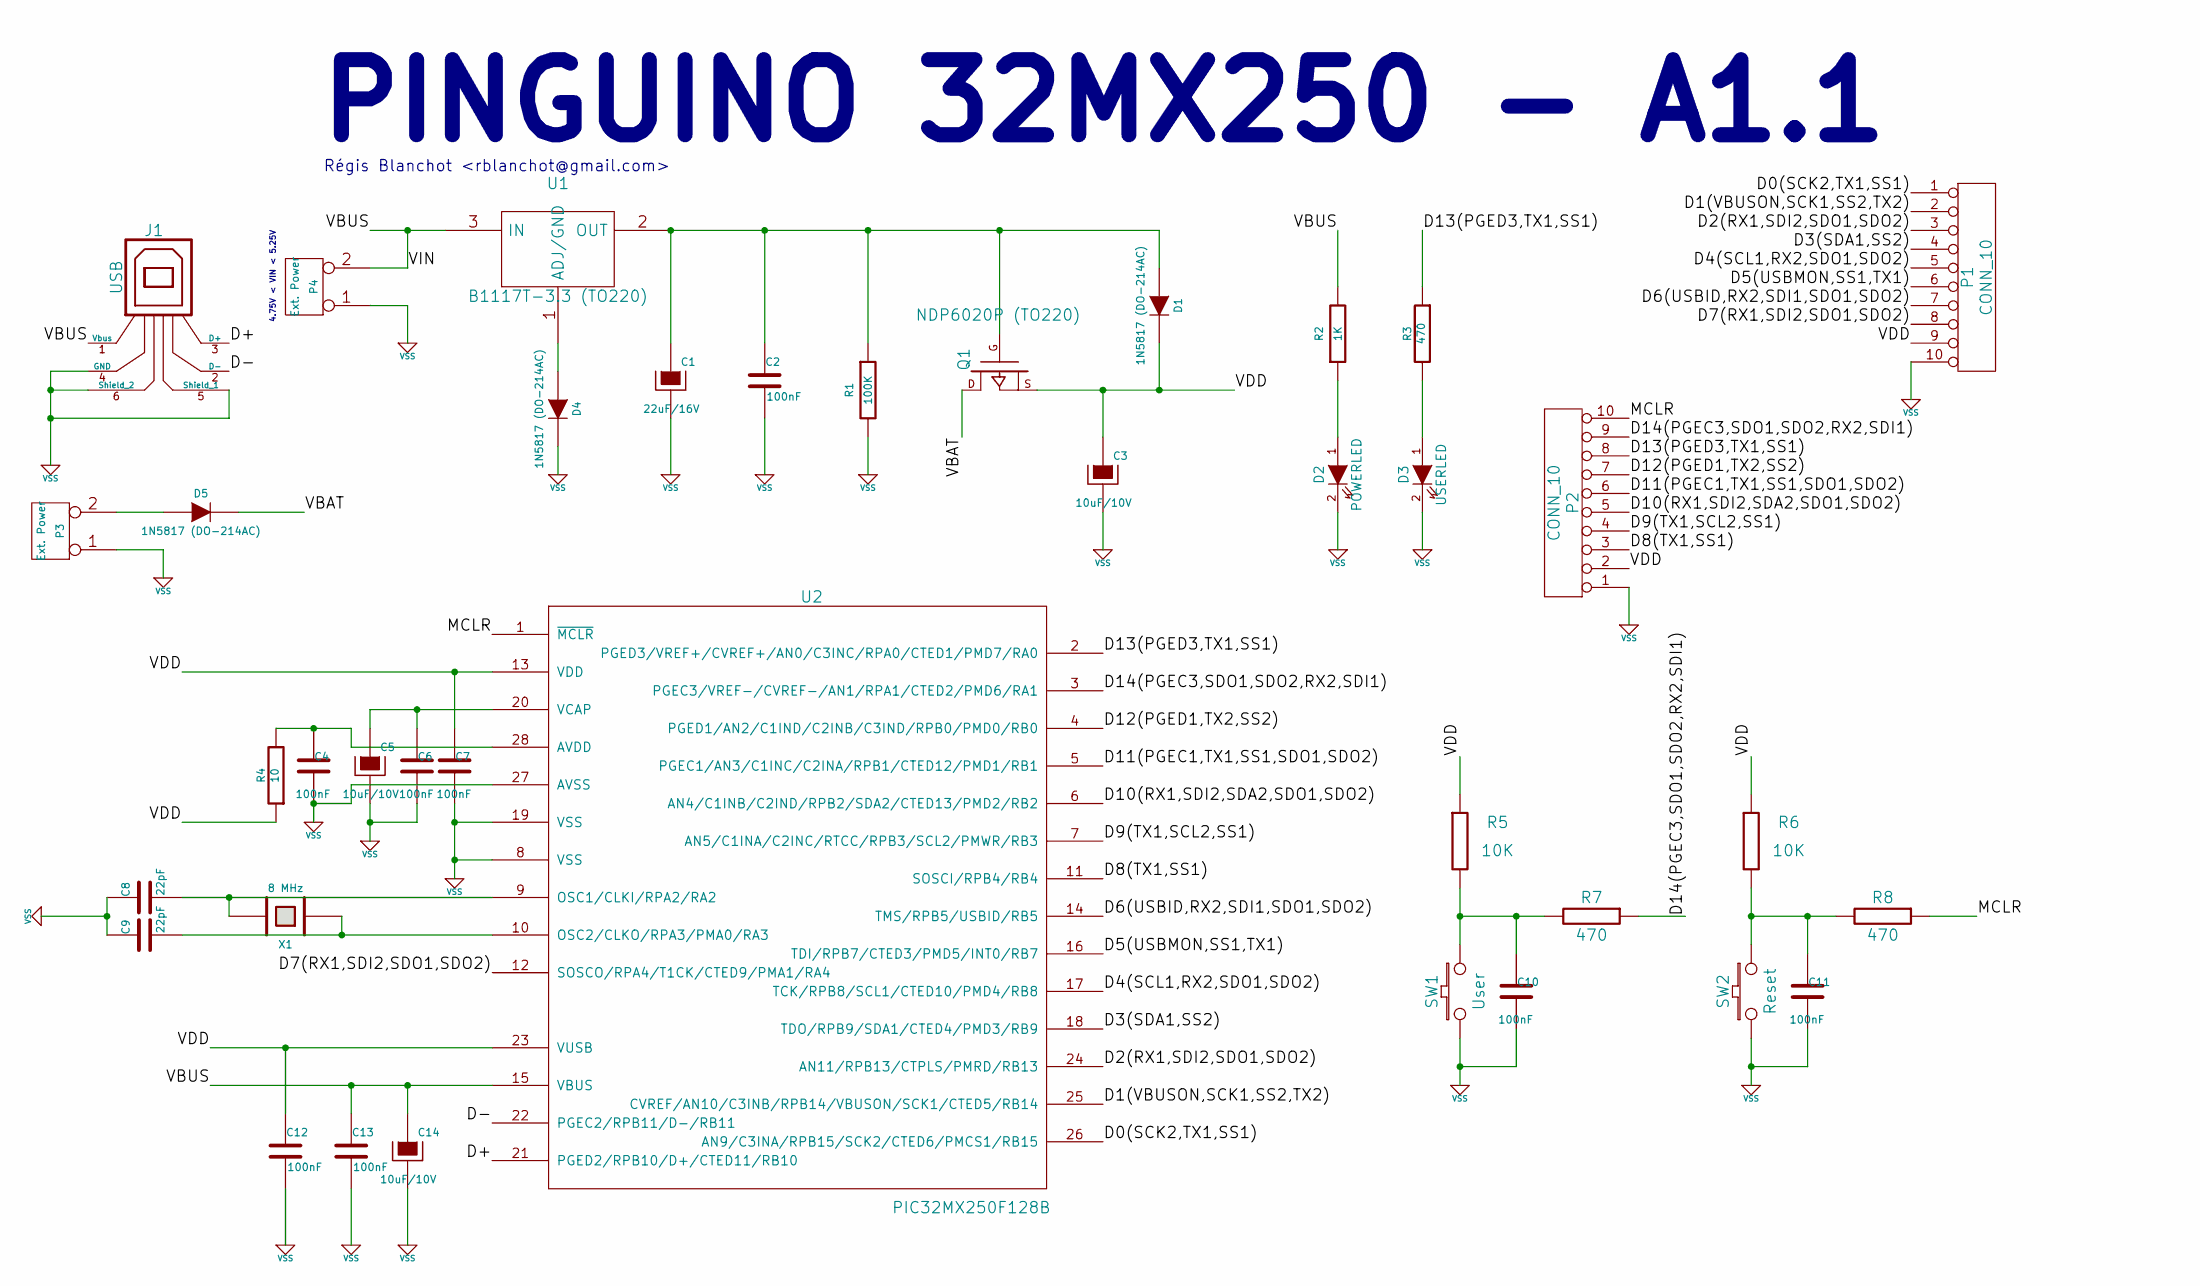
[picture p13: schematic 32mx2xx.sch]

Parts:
C1: 22uF/16V
C2, C4, C6, C7, C10, C11, C12, C13: 100nF
C3, C5, C14: 10uF/10V
C8, C9: 22pF
D1, D4, D5: 1N5817 (DO-214AC)
D2: POWERLED
D3: USERLED
J1: USB
P1, P2: CONN_10
P3, P4: Ext. Power
Q1: NDP6020P (TO220)
R1: 100K
R2: 1K
R3: 470
R4: 10
R5, R6: 10K
R7, R8: 470
SW1: User
SW2: Reset
U1: B1117T-3.3 (TO220)
U2: PIC32MX250F128B
X1: 8 MHz

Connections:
/D0(SCK2,TX1,SS1): P1.1, U2.26 (AN9/C3INA/RPB15/SCK2/CTED6/PMCS1/RB15)
/D1(VBUSON,SCK1,SS2,TX2): P1.2, U2.25 (CVREF/AN10/C3INB/RPB14/VBUSON/SCK1/CTED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)
/D2(RX1,SDI2,SDO1,SDO2): P1.3, U2.24 (AN11/RPB13/CTPLS/PMRD/RB13)
/D3(SDA1,SS2): P1.4, U2.18 (TDO/RPB9/SDA1/CTED4/PMD3/RB9)
/D4(SCL1,RX2,SDO1,SDO2): P1.5, U2.17 (TCK/RPB8/SCL1/CTED10/PMD4/RB8)
/D5(USBMON,SS1,TX1): P1.6, U2.16 (TDI/RPB7/CTED3/PMD5/INT0/RB7)
/D6(USBID,RX2,SDI1,SDO1,SDO2): P1.7, U2.14 (TMS/RPB5/USBID/RB5)
/D7(RX1,SDI2,SDO1,SDO2): P1.8, U2.12 (SOSCO/RPA4/T1CK/CTED9/PMA1/RA4)
/D8(TX1,SS1): P2.3, U2.11 (SOSCI/RPB4/RB4)
/D9(TX1,SCL2,SS1): P2.4, U2.7 (AN5/C1INA/C2INC/RTCC/RPB3/SCL2/PMWR/RB3)
/D10(RX1,SDI2,SDA2,SDO1,SDO2): P2.5, U2.6 (AN4/C1INB/C2IND/RPB2/SDA2/CTED13/PMD2/R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)
/D11(PGEC1,TX1,SS1,SDO1,SDO2): P2.6, U2.5 (PGEC1/AN3/C1INC/C2INA/RPB1/CTED12/PMD1/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)
/D12(PGED1,TX2,SS2): P2.7, U2.4 (PGED1/AN2/C1IND/C2INB/C3IND/RPB0/PMD0/R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)
/D13(PGED3,TX1,SS1): P2.8, R3.1, U2.2 (PGED3/VREF+/CVREF+/AN0/C3INC/RPA0/CTED1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)
/D14(PGEC3,SDO1,SDO2,RX2,SDI1): P2.9, R7.1, U2.3 (PGEC3/VREF-/CVREF-/AN1/RPA1/CTED2/PMD6/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)
/D+: J1.3 (D+), U2.21 (PGED2/RPB10/D+/CTED11/RB10)
/D-: J1.2 (D-), U2.22 (PGEC2/RPB11/D-/RB11)
/MCLR: P2.10, R8.1, U2.1 (~MCLR~)
/VBAT: D5.2 (K), Q1.D
/VBUS: C13.1, C14.1, J1.1 (Vbus), P4.2 (PM), R2.2, U1.3 (IN), U2.15 (VBUS)
/VDD: C3.1, C7.1, C12.1, D1.2 (K), P1.9, P2.2, Q1.S, R4.1, R5.1, R6.1, U2.13 (VDD), U2.23 (VUSB)
unnamed: C1.1, C2.1, D1.1 (A), Q1.G, R1.1, U1.2 (OUT)
unnamed: C4.1, R4.2, U2.28 (AVDD)
unnamed: C5.1, C6.1, U2.20 (VCAP)
unnamed: C8.2, U2.9 (OSC1/CLKI/RPA2/RA2), X1.2
unnamed: C9.2, U2.10 (OSC2/CLKO/RPA3/PMA0/RA3), X1.1
unnamed: C10.1, R5.2, R7.2, SW1.2
unnamed: C11.1, R6.2, R8.2, SW2.2
unnamed: D2.1 (A), R2.1
unnamed: D3.1 (A), R3.2
unnamed: D4.1 (A), U1.1 (ADJ/GND)
unnamed: D5.1 (A), P3.2 (PM)
VSS: C1.2, C2.2, C3.2, C4.2, C5.2, C6.2, C7.2, C8.1, C9.1, C10.2, C11.2, C12.2, C13.2, C14.2, D2.2 (K), D3.2 (K), D4.2 (K), J1.4 (GND), J1.5 (Shield_1), J1.6 (Shield_2), P1.10, P2.1, P3.1, P4.1, R1.2, SW1.1, SW2.1, U2.8 (VSS), U2.19 (VSS), U2.27 (AVSS)

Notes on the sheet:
Régis Blanchot <rblanchot@gmail.com>
PINGUINO 32MX250 - A1.1
4.75V < VIN < 5.25V

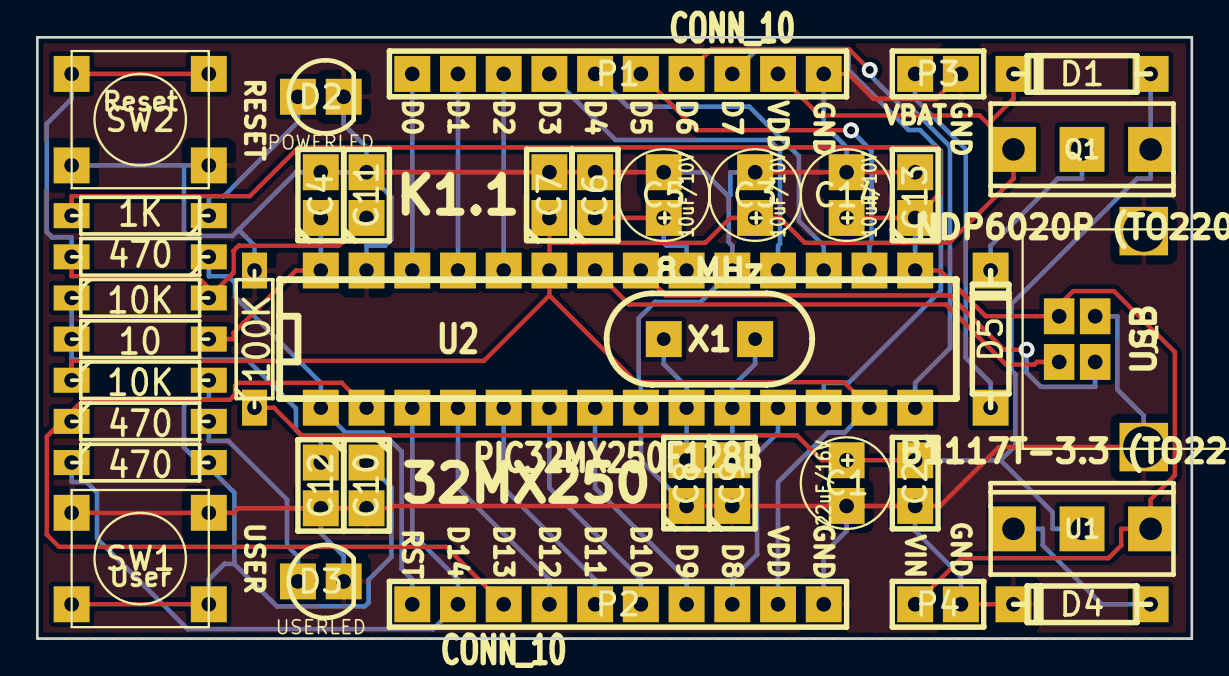
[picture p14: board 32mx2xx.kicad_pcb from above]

Board: 2 copper layers, 64.1 x 33.4 mm, 40 parts (1 on the bottom side), 33 nets.

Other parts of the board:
G2: LOGO; Logo_silk_OSHW_6x6mm
VAL: logo1in

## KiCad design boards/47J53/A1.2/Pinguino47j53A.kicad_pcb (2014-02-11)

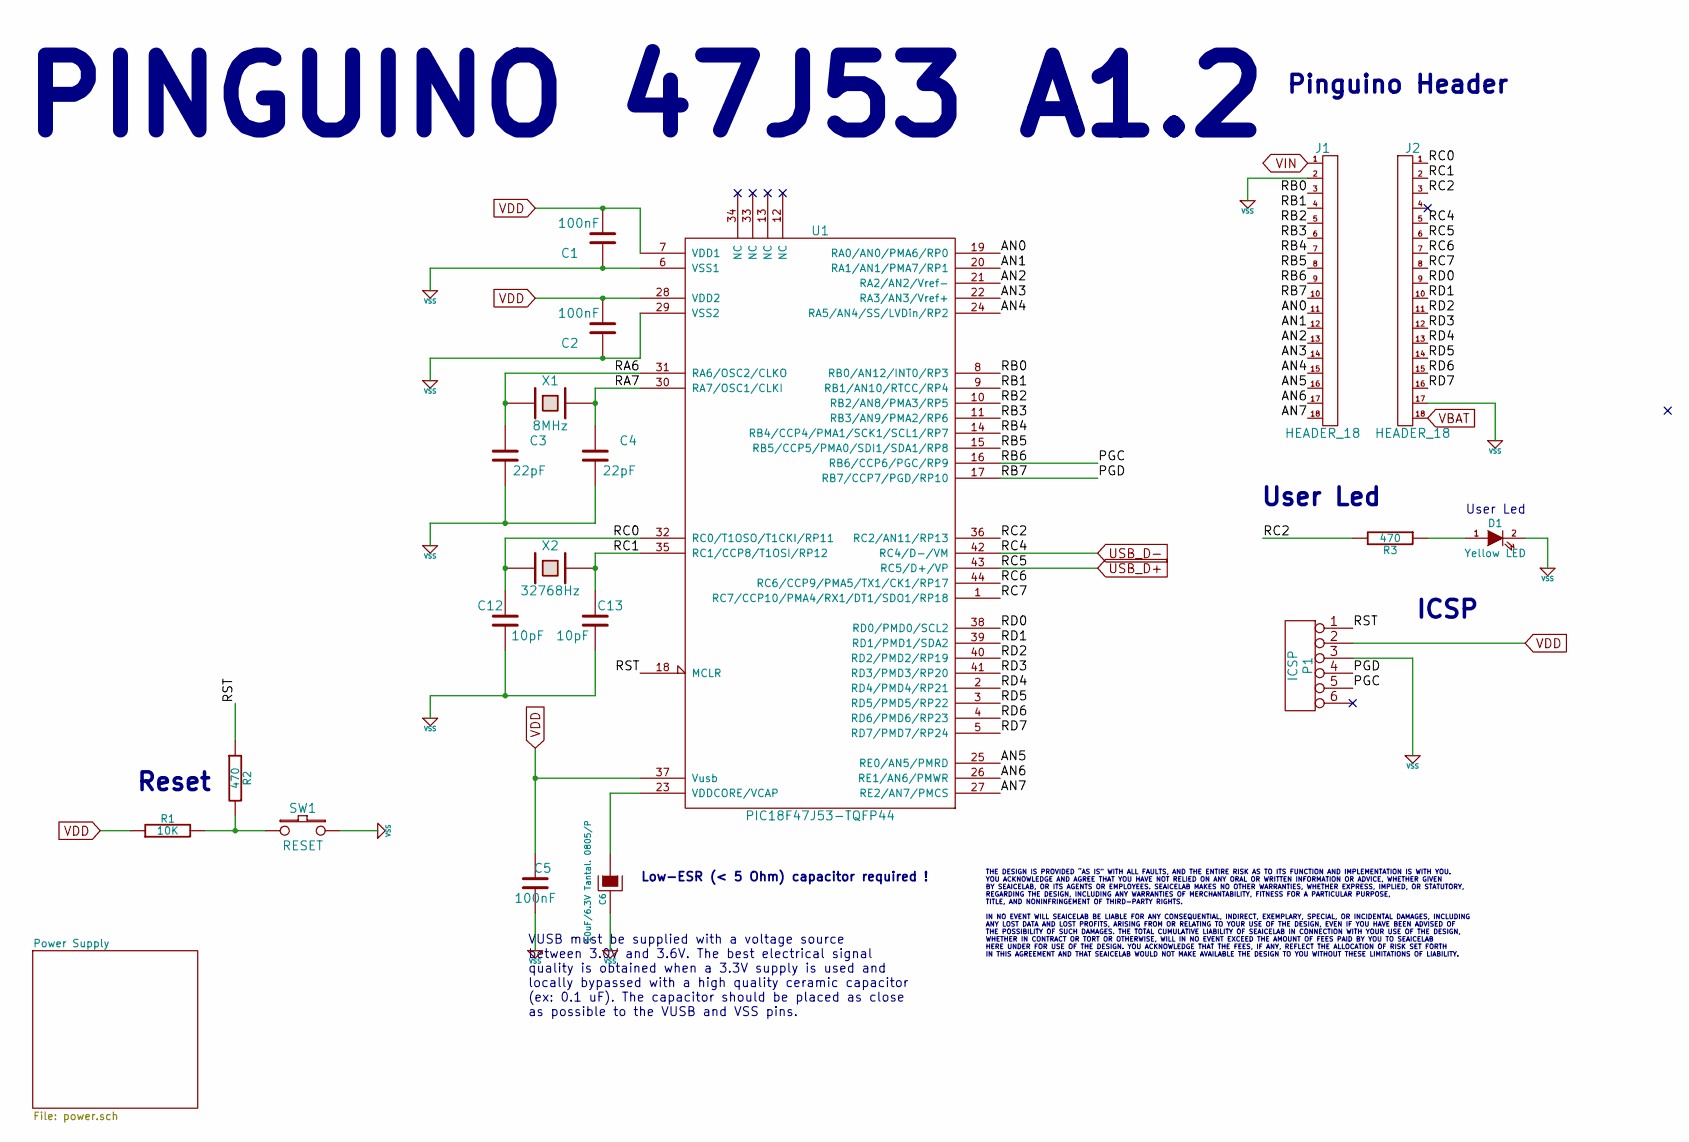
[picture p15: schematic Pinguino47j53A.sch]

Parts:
C1, C2, C5: 100nF
C3, C4: 22pF
C6: 10uF/6.3V Tantal. 0805/P
C12, C13: 10pF
D1: Yellow LED
J1, J2: HEADER_18
P1: ICSP
R1: 10K
R2, R3: 470
SW1: RESET
U1: PIC18F47J53-TQFP44
X1: 8MHz
X2: 32768Hz

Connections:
/AN0: J1.11, U1.19 (RA0/AN0/PMA6/RP0)
/AN1: J1.12, U1.20 (RA1/AN1/PMA7/RP1)
/AN2: J1.13, U1.21 (RA2/AN2/Vref-)
/AN3: J1.14, U1.22 (RA3/AN3/Vref+)
/AN4: J1.15, U1.24 (RA5/AN4/SS/LVDin/RP2)
/AN5: J1.16, U1.25 (RE0/AN5/PMRD)
/AN6: J1.17, U1.26 (RE1/AN6/PMWR)
/AN7: J1.18, U1.27 (RE2/AN7/PMCS)
/PGC: J1.9, P1.5, U1.16 (RB6/CCP6/PGC/RP9)
/PGD: J1.10, P1.4, U1.17 (RB7/CCP7/PGD/RP10)
/RA6: C3.1, U1.31 (RA6/OSC2/CLKO), X1.1
/RA7: C4.1, U1.30 (RA7/OSC1/CLKI), X1.2
/RB0: J1.3, U1.8 (RB0/AN12/INT0/RP3)
/RB1: J1.4, U1.9 (RB1/AN10/RTCC/RP4)
/RB2: J1.5, U1.10 (RB2/AN8/PMA3/RP5)
/RB3: J1.6, U1.11 (RB3/AN9/PMA2/RP6)
/RB4: J1.7, U1.14 (RB4/CCP4/PMA1/SCK1/SCL1/RP7)
/RB5: J1.8, U1.15 (RB5/CCP5/PMA0/SDI1/SDA1/RP8)
/RC0: C12.1, J2.1, U1.32 (RC0/T1OSO/T1CKI/RP11), X2.1
/RC1: C13.1, J2.2, U1.35 (RC1/CCP8/T1OSI/RP12), X2.2
/RC2: J2.3, R3.2, U1.36 (RC2/AN11/RP13)
/RC6: J2.7, U1.44 (RC6/CCP9/PMA5/TX1/CK1/RP17)
/RC7: J2.8, U1.1 (RC7/CCP10/PMA4/RX1/DT1/SDO1/RP18)
/RD0: J2.9, U1.38 (RD0/PMD0/SCL2)
/RD1: J2.10, U1.39 (RD1/PMD1/SDA2)
/RD2: J2.11, U1.40 (RD2/PMD2/RP19)
/RD3: J2.12, U1.41 (RD3/PMD3/RP20)
/RD4: J2.13, U1.2 (RD4/PMD4/RP21)
/RD5: J2.14, U1.3 (RD5/PMD5/RP22)
/RD6: J2.15, U1.4 (RD6/PMD6/RP23)
/RD7: J2.16, U1.5 (RD7/PMD7/RP24)
/RST: P1.1, R2.1, U1.18 (MCLR)
unnamed: D1.1 (A), R3.1
unnamed: R1.2, R2.2, SW1.1
unnamed: C6.1, U1.23 (VDDCORE/VCAP)
USB_D+: J2.6, U1.43 (RC5/D+/VP); also elsewhere on the board
USB_D-: J2.5, U1.42 (RC4/D-/VM); also elsewhere on the board
VBAT: J2.18; also elsewhere on the board
VBUS: J1.1; also elsewhere on the board
VDD: C1.2, C2.2, C5.1, P1.2, R1.1, U1.7 (VDD1), U1.28 (VDD2), U1.37 (Vusb); also elsewhere on the board
VSS: C1.1, C2.1, C3.2, C4.2, C5.2, C6.2, C12.2, C13.2, D1.2 (K), J1.2, J2.17, P1.3, SW1.2, U1.6 (VSS1), U1.29 (VSS2); also elsewhere on the board

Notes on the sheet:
VUSB must be supplied with a voltage source between 3.0V and 3.6V. The best electrical signal quality is obtained when a 3.3V supply is used and locally bypassed with a high quality ceramic capacitor (ex: 0.1 uF). The capacitor should be placed as close as possible to the VUSB and VSS pins.
Low-ESR (< 5 Ohm) capacitor required !
PINGUINO 47J53 A1.2
User Led
Reset
THE DESIGN IS PROVIDED “AS IS” WITH ALL FAULTS, AND THE ENTIRE RISK AS TO ITS FUNCTION AND IMPLEMENTATION IS WITH YOU. YOU ACKNOWLEDGE AND AGREE THAT YOU HAVE NOT RELIED ON ANY ORAL OR WRITTEN INFORMATION OR ADVICE, WHETHER GIVEN BY SEAICELAB, OR ITS AGENTS OR EMPLOYEES. SEAICELAB MAKES NO OTHER WA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
ICSP
Pinguino Header

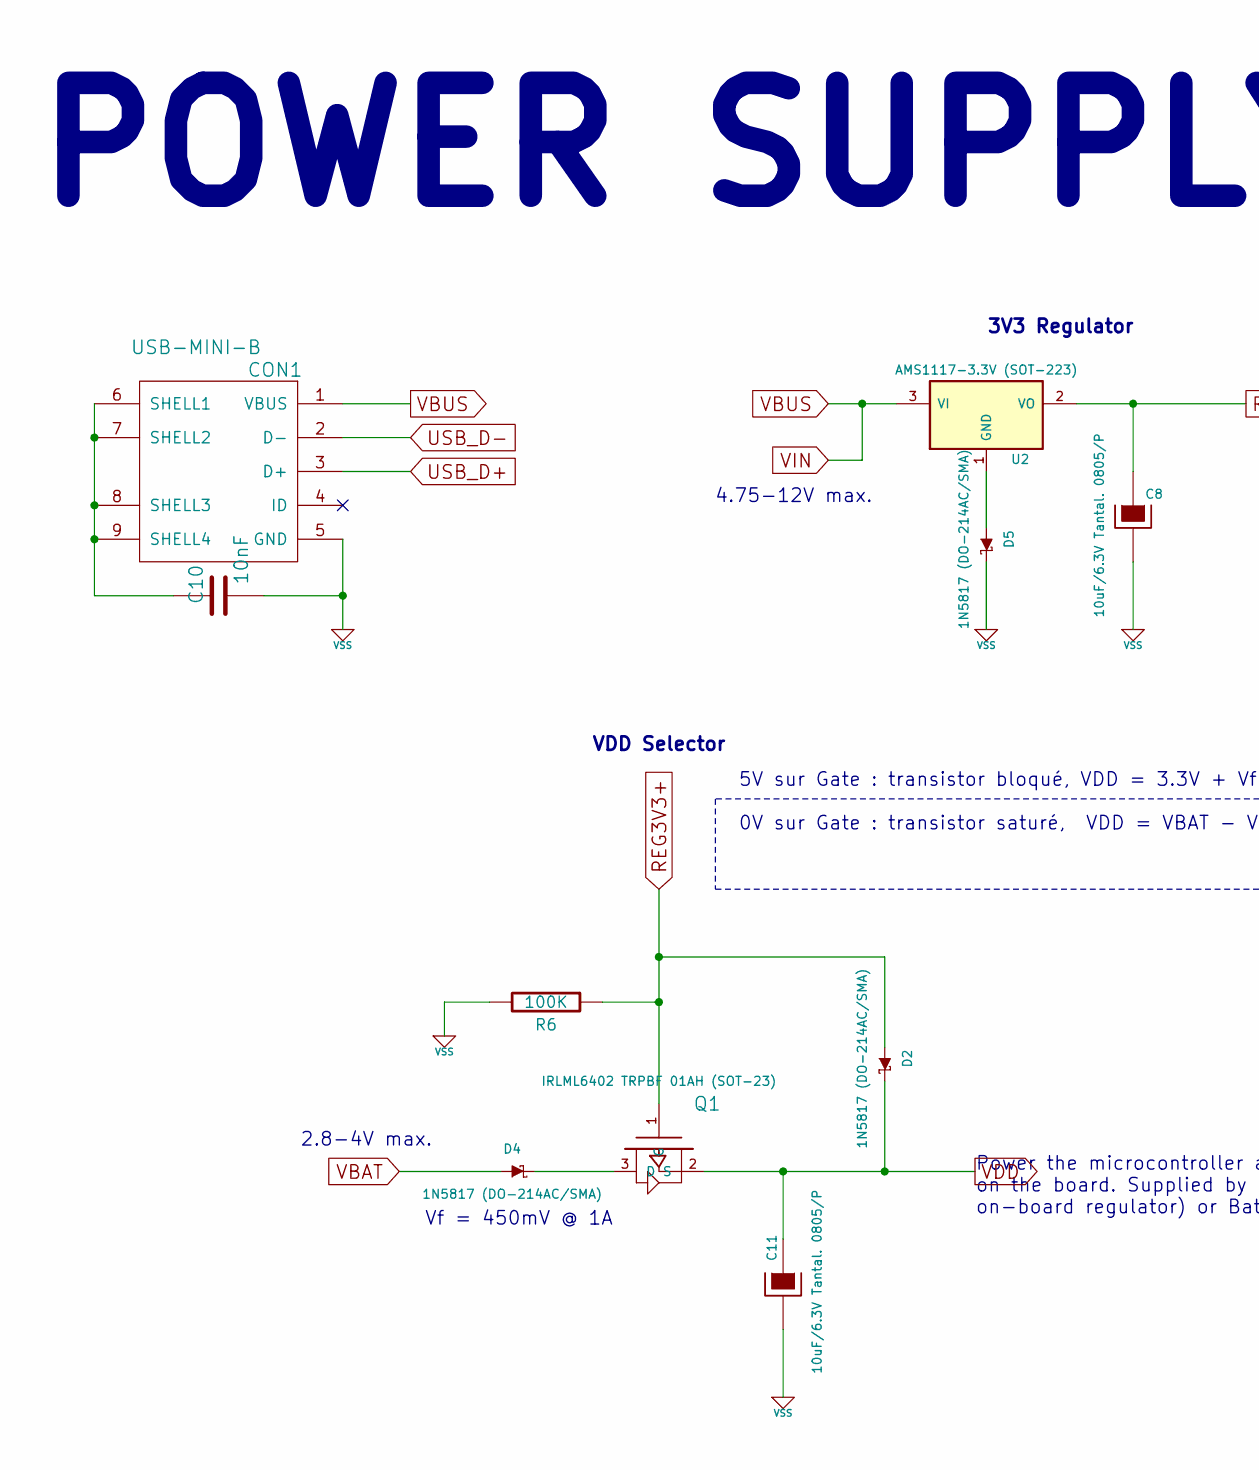
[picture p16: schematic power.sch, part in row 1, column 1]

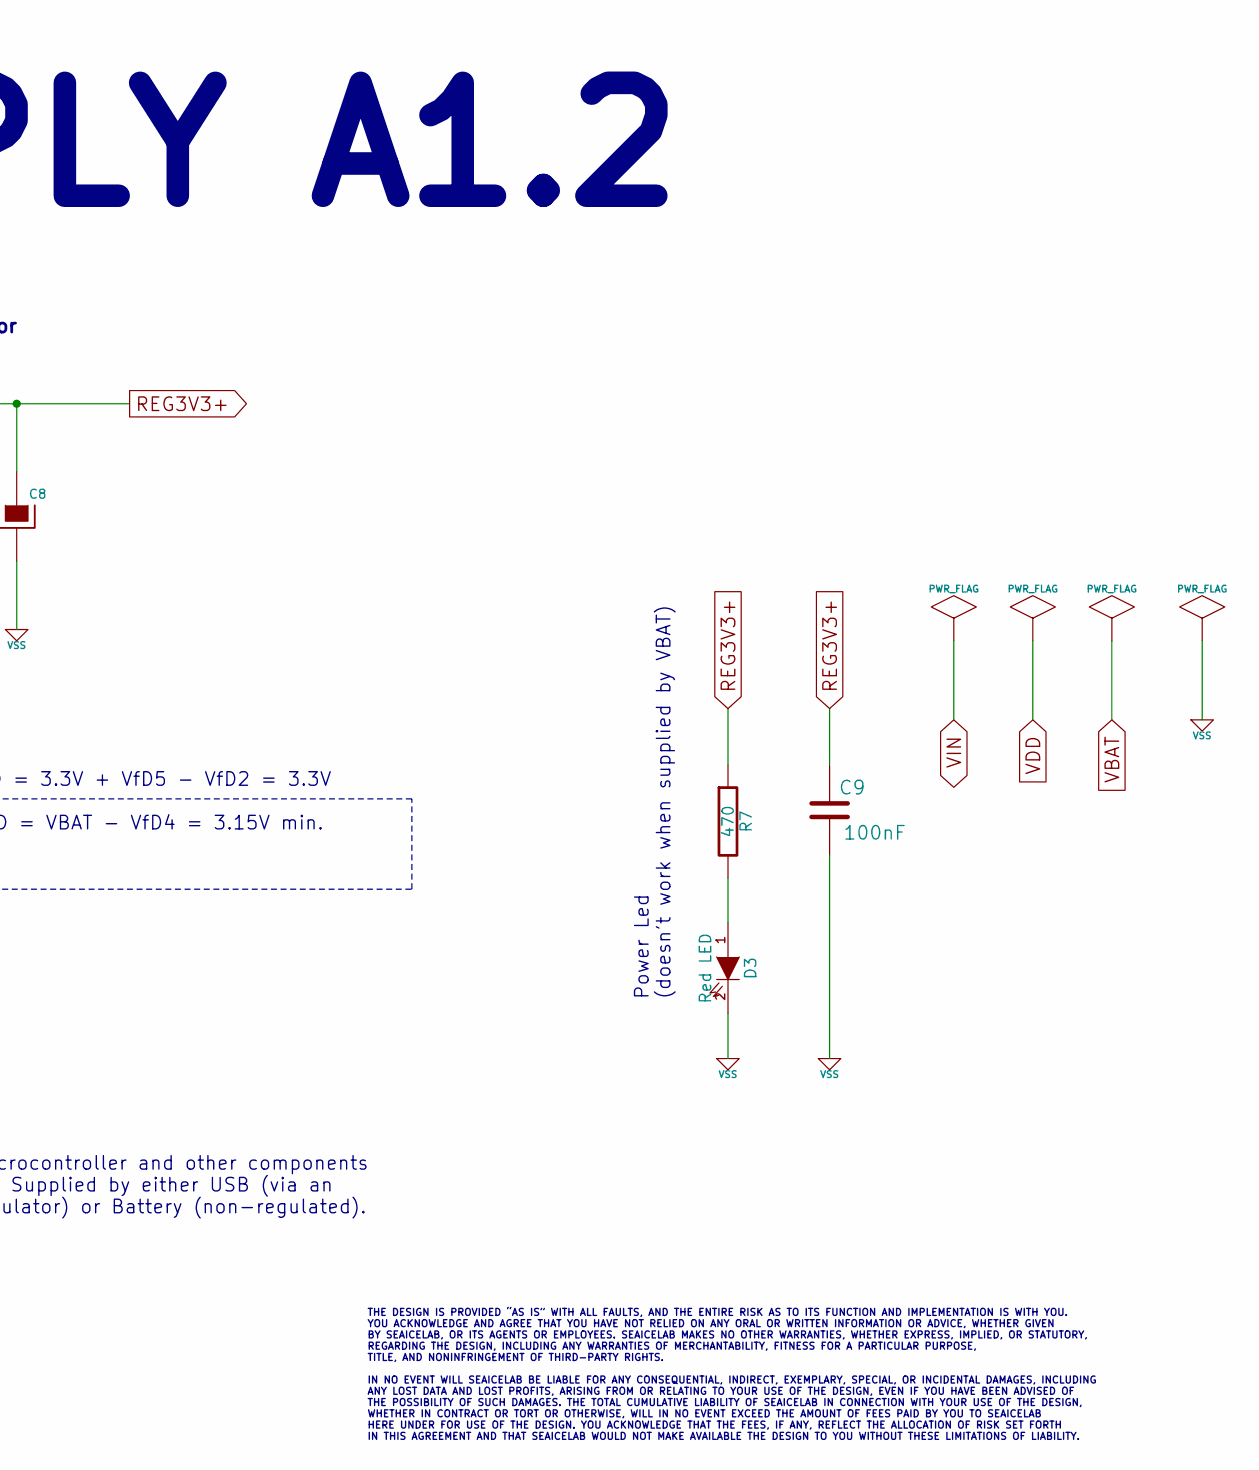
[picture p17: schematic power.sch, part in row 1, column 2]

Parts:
C8, C11: 10uF/6.3V Tantal. 0805/P
C9: 100nF
C10: 10nF
CON1: USB-MINI-B
D2, D4, D5: 1N5817 (DO-214AC/SMA)
D3: Red LED
Q1: IRLML6402 TRPBF 01AH (SOT-23)
R6: 100K
R7: 470
U2: AMS1117-3.3V (SOT-223)

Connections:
unnamed: D5.1 (A), U2.1 (GND)
unnamed: D4.2 (K), Q1.3 (D)
unnamed: C10.1, CON1.6 (SHELL1), CON1.7 (SHELL2), CON1.8 (SHELL3), CON1.9 (SHELL4)
unnamed: D3.1 (A), R7.2
REG3V3+: C8.1, C9.2, D2.1 (A), Q1.1 (G), R6.1, R7.1, U2.2 (VO)
USB_D+: CON1.3 (D+); also elsewhere on the board
USB_D-: CON1.2 (D-); also elsewhere on the board
VBAT: D4.1 (A); also elsewhere on the board
VBUS: CON1.1 (VBUS), U2.3 (VI); also elsewhere on the board
VDD: C11.1, D2.2 (K), Q1.2 (S); also elsewhere on the board
VSS: C8.2, C9.1, C10.2, C11.2, CON1.5 (GND), D3.2 (K), D5.2 (K), R6.2; also elsewhere on the board

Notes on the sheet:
Vf = 450mV @ 1A
2.8-4V max.
Power the microcontroller and other components on the board. Supplied by either USB (via an on-board regulator) or Battery (non-regulated).
THE DESIGN IS PROVIDED “AS IS” WITH ALL FAULTS, AND THE ENTIRE RISK AS TO ITS FUNCTION AND IMPLEMENTATION IS WITH YOU. YOU ACKNOWLEDGE AND AGREE THAT YOU HAVE NOT RELIED ON ANY ORAL OR WRITTEN INFORMATION OR ADVICE, WHETHER GIVEN BY SEAICELAB, OR ITS AGENTS OR EMPLOYEES. SEAICELAB MAKES NO OTHER WA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
VDD Selector
POWER SUPPLY A1.2
Power Led (doesn't work when supplied by VBAT)
5V sur Gate : transistor bloqué, VDD = 3.3V + VfD5 - VfD2 = 3.3V 0V sur Gate : transistor saturé, VDD = VBAT - VfD4 = 3.15V min.
3V3 Regulator
4.75-12V max.

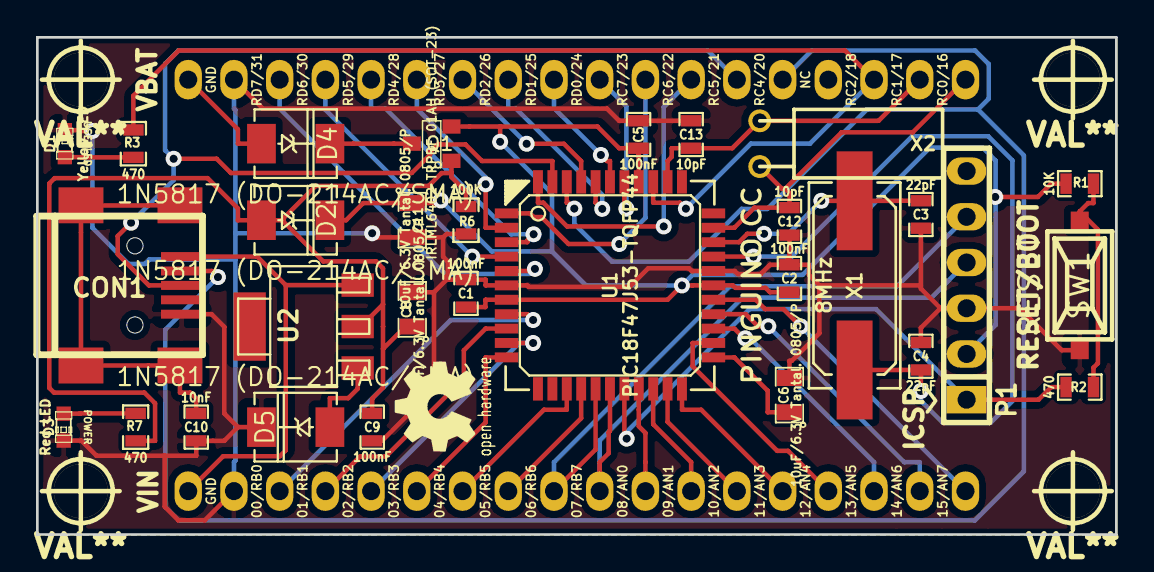
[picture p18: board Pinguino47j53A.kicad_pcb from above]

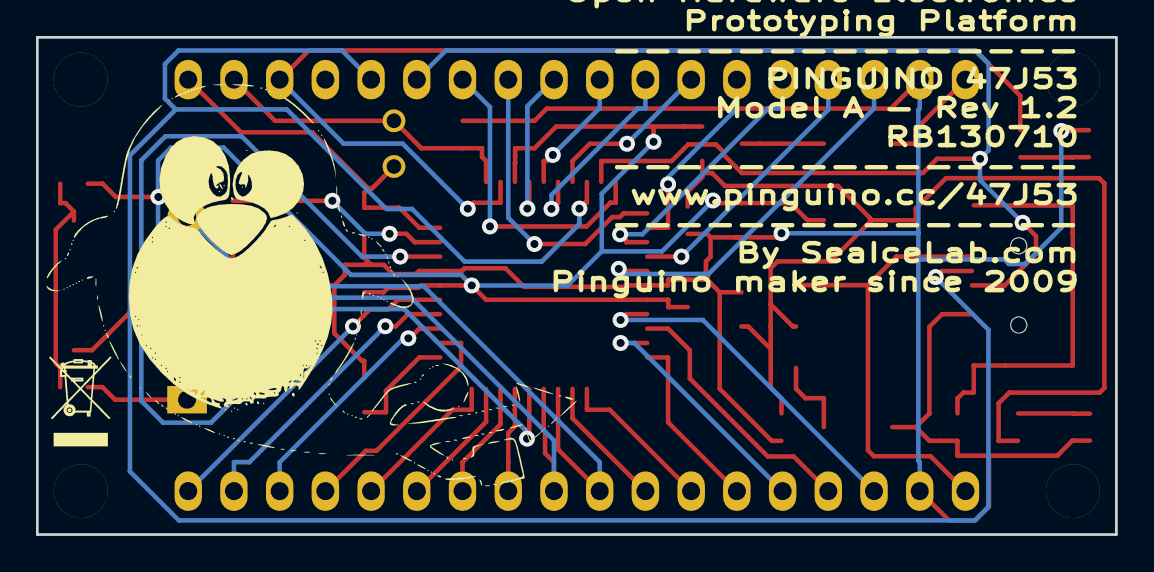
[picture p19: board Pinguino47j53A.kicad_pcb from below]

Board: 2 copper layers, 59.9 x 27.6 mm, 38 parts (4 on the bottom side), 46 nets.

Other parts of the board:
G1: LOGO
G2: LOGO; Logo_silk_WEEE_3.4x5mm
hole_3mm_1, hole_3mm_2, hole_3mm_3, hole_3mm_4: VAL**; hole_3mm

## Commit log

2014-02-11 new file: LICENSE new file: boards/26J50/K1.0/$savepcb.000 new file: boards/26J50/K1.0/$savepcb.brd new file: boards/26J50/K1.0/BoM.odt new file: boards/26J50/K1.0/Pinguino26j50-Contours_PCB.gbr new 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
    [$savepcb.brd, 32mx2xx.brd, 32mx2xx.csv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]
2014-07-08 Added New Pinguino 45K50 CAD Files
    [$savepcb.brd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]
2021-04-24 feat(3d): Added 3D image for 32MX250 and 47J53 boards
